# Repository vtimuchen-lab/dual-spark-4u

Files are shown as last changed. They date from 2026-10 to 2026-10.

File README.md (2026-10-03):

# dual-spark-4u — 5U-модуль с 2 × MSI EdgeXpert AI (DGX Spark-class) и раздельным охлаждением для 18U шкафа

Параметрический OpenSCAD-проект самостоятельного 5U-узла: фронтальная панель
ЦМО ФП-5 с двумя вырезами под 140-мм вентиляторы, алюминиевая base_plate на
полке шкафа, два holder'а (адаптация
[alexliesenfeld/dgx-spark-printables](https://github.com/alexliesenfeld/dgx-spark-printables),
CC BY-NC 4.0), два независимых воздуховода 140 → передняя решётка MSI, свободный
выхлоп в горячую зону шкафа. Имя репозитория историческое: v1 проектировалась
под 4U-корпус (`docs/TZ_v1_chassis.md`), v2 — модуль в шкафу (`docs/TZ.md`).

```
[решётка ARCTIC 140] → [ФП-5] → [Arctic P14 Pro PST 27] → [duct 120] → [EPDM 5] → [MSI 151] → [выхлоп ≥ 90]
                                   × 2 трака, оси x = ±98 от центра панели
```

## Статус: PREVIEW — ждёт пять замеров шкафа

Сборка модуля, base_plate и вертикальная разметка панели **не собираются**, пока
в `scad/params.scad` стоят `undef` для `rack_opening_w`, `shelf_top_z`,
`shelf_depth`, `panel_t`, `panel_hole_pitch_v` (`docs/03_measure_checklist.md`,
п.1–5). Детали, не зависящие от шкафа (holder, воздуховод, заслонка, уголок,
стойка DC), собираются и лежат в `stl/*_PREVIEW.stl`; рендеры сборки сделаны на
подстановочных значениях, перечисленных в `scripts/export_all.sh` и
`docs/02_layout.md` §7.

| Документ | Что |
|---|-----|
| `docs/TZ.md` | ТЗ v2 (принятые решения) |
| `CLAUDE.md` | решения, открытые вопросы, журнал |
| `docs/01_analysis.md` | MSI EdgeXpert, исходник holder'а, опыт сообщества (+архив анализа 4U) |
| `docs/02_layout.md` | размерная схема модуля, координаты, проверки |
| `docs/03_measure_checklist.md` | что измерить (шкаф, панель, MSI, покупные) |
| `docs/04_aero_estimate.md` | расход, характеристика P14 Pro PST, рабочая точка, байпас, дверь шкафа |
| `docs/05_bom_hardware.md` | печатные/покупные части, крепёж, длина болтов |
| `docs/06_dimensions.md` | таблица размеров |
| `docs/07_rack_layout.md` | раскладка 18U, холодная/горячая зона, датчики, установка/снятие |
| `docs/drawings/` | `panel_fp5`, `base_plate`, `side_view`, `top_view` (SVG + PNG) |
| `docs/renders/` | 3D-превью (`*_PREVIEW.png`) |

## Ключевые размеры

| | мм |
|---|---|
| Трак / шаг / пара | 181 / 196 / 377 |
| Длина модуля от задней плоскости панели | 393 (шкаф 600) |
| Ось вентилятора над полкой / над плитой | 78 / 75 (= ось MSI) |
| Вырезы панели | 2 × Ø138 на 143.3 и 339.3 от левого края; ось по вертикали = `shelf_top_z` + 78 ∈ [90; 131.5] |
| Воздуховод | 135×135 → 145×57, plenum 50 + nozzle 70, стенка 2.4 |
| Болт сэндвича | M4×40 при panel_t 1.0–2.0 |
| Контроллеры | в рамках на лицевой стороне панели над вентиляторами; полоса = 221.5 − `shelf_top_z` − 150 |

## Файлы

```
scad/params.scad          все параметры [SRC]/[ASSM]/TO_MEASURE(undef), производные, part_checks()/rack_checks()
scad/lib/shapes.scad      примитивы, лофт, макеты
scad/edgexpert_holder.scad  holder (part=holder|holder_with_device|baffle|holder_with_baffle)
scad/duct.scad            воздуховод (part=duct|duct_a|duct_b|duct_section)
scad/front_panel.scad     ФП-5 с вырезами (part=panel|panel_2d) — требует TO_MEASURE
scad/base_plate.scad      base_plate (требует TO_MEASURE), panel_bracket, dc_jack_bracket
scad/ctrl_bezel.scad      рамка термоконтроллера на лицевой стороне ФП-5 (требует ctrl_w/h/d)
scad/assembly.scad        модуль (part=module|exploded|track|printables)
scad/fan_bracket.scad     ОПЦИЯ: рамка для настольного стенда
stl/                      *_PREVIEW.stl до заполнения TO_MEASURE
scripts/export_all.sh     пересборка STL, рендеров, чертежей (суффикс PREVIEW автоматически)
scripts/make_drawings.py  чертежи из params.scad
```

## Как пользоваться

1. Измерить п.1–5 (и по возможности B/C) из `docs/03_measure_checklist.md`,
   вписать в `scad/params.scad` вместо `undef`.
2. `./scripts/export_all.sh` — при полных параметрах суффикс `_PREVIEW`
   исчезает, рендеры и чертежи пересчитываются на реальных размерах; в выводе не
   должно быть `ERROR: Assertion`.
3. Резать панель и сверлить плиту по `docs/drawings/panel_fp5.svg` и
   `base_plate.svg`; печатать по `docs/05_bom_hardware.md` (PETG прототип, ASA
   финал); собирать по `docs/07_rack_layout.md` §5.

Ручной экспорт одной детали:

```sh
openscad -o stl/edgexpert_holder.stl scad/edgexpert_holder.scad
openscad -o stl/bypass_baffle_050.stl -D 'part="baffle"' -D bypass_block=0.5 scad/edgexpert_holder.scad
openscad -o stl/duct.stl scad/duct.scad
openscad -o stl/panel_bracket.stl -D 'part="panel_bracket"' scad/base_plate.scad
```

## Лицензия

Производная работа от dgx-spark-printables (CC BY-NC 4.0, Alexander Liesenfeld) —
на тех же условиях, некоммерчески, с указанием автора исходника.

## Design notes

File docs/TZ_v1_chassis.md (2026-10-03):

# ТЗ v1 (исходное): система размещения и принудительного охлаждения 2× MSI EdgeXpert AI / DGX Spark-class в одном 4U корпусе

> Архивная версия. Заменена `docs/TZ.md` (v2: 5U-модуль в 18U шкафу).
> Текст сохранён как получен, без правок.

## 1. Цель проекта
Спроектировать внутреннюю механическую конструкцию для существующего металлического rackmount-корпуса 4U, позволяющую установить внутри два компьютера MSI EdgeXpert AI на NVIDIA GB10 и организовать для каждого отдельный управляемый воздушный тракт.
Требуется не новый корпус и не передняя rack-панель. Существующий 4U-корпус уже имеется и должен использоваться как внешнее шасси.
Основная идея:
один корпус 4U → два MSI EdgeXpert → две отдельные подставки → два независимых воздуховода → по одному 140-мм вентилятору на каждый EdgeXpert.
В качестве механической основы под каждый EdgeXpert использовать и адаптировать конструкцию holder из проекта:
`https://github.com/alexliesenfeld/dgx-spark-printables`
Основной исходник для изучения:
`spark-rack-10/dgx_spark_rack_mount.scad`
Не использовать 10-дюймовую переднюю панель этого проекта. Нужен только принцип и геометрия внутреннего holder / основания / ложемента.

## 2. Исходные данные
В репозитории для DGX Spark-class используется расчетный габарит устройства:
150 × 150 × 50,5 мм.
В исходном `spark-rack-10`:
* `device_width = 150 mm`
* `device_depth = 150 mm`
* `device_height = 50.5 mm`
* нижняя конструкция имеет вентиляционные каналы;
* имеются боковые направляющие;
* имеются задние ограничители;
* верх устройства открыт;
* holder экспортируется отдельно через `part="holder"`;
* исходная конструкция рассчитана на 2×80 мм вентилятора, расположенные перед устройством.

Размеры исходного holder приблизительно:
183 мм ширина × 182,5 мм глубина × до 88 мм высота передней части.
Эти размеры рассматривать только как исходные параметры. Перед окончательной моделью необходимо проверить реальные размеры конкретного MSI EdgeXpert AI, расположение его ножек, нижних, передних, боковых и задних вентиляционных отверстий.
Фотографии существующего 4U-корпуса предоставлены отдельно. Конструкцию проектировать именно для этого корпуса.

## 3. Что использовать из GitHub-модели
Из `spark-rack-10` необходимо взять за основу нижний holder, а именно:
* основание;
* опорные продольные элементы;
* вентиляционные каналы снизу;
* боковые направляющие;
* задние стопоры;
* принцип свободного доступа воздуха снизу и сбоку.

НЕ использовать:
* 254×88 мм front panel;
* rack ears;
* отверстия под крепление 10-inch rack;
* существующие отверстия под 2×80 мм вентиляторы;
* саму переднюю панель вообще.

Holder должен стать самостоятельной подставкой, закрепленной на металлическом дне существующего 4U-корпуса.
Желательно сделать крепление holder к корпусу съемным, например M3/M4, резьбовые заклепки, закладные гайки либо отдельная металлическая монтажная пластина.
Не рассчитывать только на клей или двусторонний скотч.

## 4. Количество оборудования
В одном корпусе устанавливаются: 2 × MSI EdgeXpert AI / GB10.
Не два rack-корпуса. Не 12 вентиляторов. Не 4×80 мм.
Основной вариант проекта: 2 × 140-мм вентилятора 12 В, по одному вентилятору на каждый EdgeXpert.
Каждый EdgeXpert имеет свой отдельный воздушный тракт.

## 5. Предпочтительное размещение EdgeXpert
Приоритетное расположение — два устройства рядом в одном горизонтальном слое, если реальные внутренние размеры корпуса позволяют.
Не размещать один EdgeXpert над другим без серьезной причины.
Причины: одинаковые условия охлаждения; прямые воздуховоды; более простой монтаж; удобный доступ к обоим устройствам; отсутствие нагрева верхнего устройства нижним; возможность снять одно устройство независимо от второго.
Ориентацию каждого MSI подобрать так, чтобы штатное направление внутреннего воздушного потока совпадало с направлением внешней вентиляции.
Желательное направление всего корпуса: перед корпуса → EdgeXpert → зад корпуса.

## 6. Основная схема охлаждения
Для каждого компьютера:
```
холодный воздух → [140×140×25 FAN] → [пленум / плавный переход] → [входные отверстия EdgeXpert]
→ [штатная система охлаждения EdgeXpert] → горячий воздух → задняя часть 4U-корпуса
```
Внешний вентилятор не должен просто обдувать весь корпус. Его воздух необходимо направить преимущественно именно к воздухозабору EdgeXpert.
При этом нельзя герметично закрывать вентиляционные отверстия устройства, которые MSI использует дополнительно снизу или по бокам.
Поэтому перед окончательным проектом требуется определить реальную аэродинамическую схему MSI EdgeXpert.

## 7. Вентиляторы
Основной расчет вести под стандартный вентилятор: 140 × 140 × 25 мм, 12 В, PWM. Один вентилятор на один EdgeXpert. Итого: 2 вентилятора на весь корпус.
Крепление вентилятора должно быть стандартным и позволять его замену без печати нового воздуховода.
Предусмотреть: стандартные 140-мм монтажные отверстия; M4 или стандартные fan screws; возможность установки резиновых виброразвязок; съемную рамку; опциональную защитную решетку; опциональный воздушный фильтр только при малом аэродинамическом сопротивлении.
Не проектировать плотную декоративную решетку перед крыльчаткой.

## 8. Воздуховод
Необходимы два отдельных воздуховода: FAN 1 → duct 1 → EdgeXpert 1; FAN 2 → duct 2 → EdgeXpert 2.
Не делать один общий воздуховод с двумя входами без специального CFD-обоснования.
Каждый канал должен начинаться с 140×140 мм. Конечная геометрия выхода должна определяться по реальному воздухозабору MSI EdgeXpert, а не только по внешнему размеру корпуса 150×50,5 мм.
Предварительный ориентир выхода воздуховода: около 150–155 мм шириной, высота определяется реальной зоной воздухозабора. Не считать `152 × 54 мм` окончательным размером.

## 9. Геометрия перехода
Не делать резкое сужение. Нужен плавный diffuser/nozzle. Допустимая исходная длина воздуховода: 100–180 мм.
Если глубины достаточно, предпочтительнее плавная форма с большим радиусом, чем короткая воронка.
Избегать: острых внутренних углов; ступенек; резких изменений площади; плоской стенки непосредственно за ступицей вентилятора.
Внутренние переходы желательно делать радиусными. Ориентировочный внутренний радиус: R15–R25 мм или больше.

## 10. Пленум за вентилятором
Не ставить EdgeXpert непосредственно вплотную к крыльчатке 140 мм. Желательно иметь участок выравнивания потока: примерно 40–80 мм от плоскости вентилятора до начала критического сужения/входа устройства.
При необходимости добавить внутренние направляющие лопатки: тонкие; с закругленной передней кромкой; без значительного сопротивления; распределяющие поток по ширине воздухозабора.

## 11. Задняя часть корпуса
После EdgeXpert горячий воздух должен иметь свободное пространство для выхода. Минимально желательно 70–100 мм свободной зоны после устройства.
Не ставить непосредственно за выходом EdgeXpert глухую стенку.
Предусмотреть возможный будущий вариант: общий задний exhaust plenum; 1×140 мм exhaust; либо 2×120/140 мм exhaust. Первый прототип должен работать и без дополнительной задней принудительной вытяжки. Задний exhaust-модуль опциональный.

## 12. Боковые и нижние отверстия MSI
Нельзя проектировать holder так, чтобы: закрыть нижний воздухозабор; перекрыть боковые решетки; полностью зажать корпус MSI пластиковыми стенками.
Перед моделированием изучить: реальную нижнюю поверхность MSI EdgeXpert; расположение ножек; решетки; вход/выход воздуха; разъемы; кнопку питания; доступ к LAN/USB/питанию.

## 13. Основание / holder
На каждый EdgeXpert отдельный holder. Holder должен: удерживать от бокового и продольного смещения; не пережимать корпус; сохранять вентиляцию снизу; позволять снять устройство; крепиться к металлическому основанию корпуса; выдерживать транспортировку.
Толщина печатных несущих стенок: 4–5 мм. Нижние элементы: 4–5 мм. Аэродинамическая оболочка воздуховода: 2–3 мм.

## 14. Разделение holder и воздуховода
Модульность: [fan bracket] + [air duct] + [EdgeXpert holder], соединение винтами/защелками/пазами.

## 15. Материал
PETG, ASA или ABS. PLA не использовать. PETG для прототипа, ASA для окончательной версии.

## 16. Электрика вентиляторов
12 В PWM, 4-pin. Место для PWM-контроллера, температурного датчика, распределителя питания, кабелей. Электроника не в горячем выхлопе. Ручное и автоматическое управление оборотами.

## 17. Возможные датчики
Перед воздухозабором EdgeXpert; за EdgeXpert; внутри корпуса; при необходимости — duct.

## 18. Расположение в существующем 4U корпусе
Определить по фото: внутреннюю ширину, высоту, глубину, положение HDD-корзины, существующие вентиляторы, заднюю панель, PCI-слоты, кабели, переднюю панель. Указать, что демонтировать. Не предлагать новый корпус, пока не доказано обратное.

## 19. Предпочтительная компоновка сверху
Два тракта рядом: [140 FAN] → [DUCT] → [MSI #1] →; [140 FAN] → [DUCT] → [MSI #2] → rear exhaust. Потоки независимые.

## 20. Ориентация корпуса MSI
Определить реальный intake → internal airflow → exhaust, затем ориентировать устройство в holder.

## 21. CFD / аэродинамическая оценка
Инженерная оценка: площади, отношение площадей, скорость, зоны рециркуляции, потери на переходе, ступица, решетка. Указать проблемные места. Не выдавать CFM вентилятора за расход через EdgeXpert.

## 22. Передняя панель существующего корпуса
Оценить достаточность вентиляционных отверстий дверцы для двух 140-мм. При необходимости — увеличение перфорации, сетка, два окна, съемный фильтр. Вентиляторы могут стоять глубже внутри корпуса.

## 23. Шум
Низкие обороты в idle; PWM только под нагрузкой; без свиста; расстояние от решетки; без близкой перфорации перед лопастями.

## 24. Сервисное обслуживание
Снять крышку; вынуть каждый EdgeXpert отдельно; заменить вентилятор; снять duct; доступ к разъемам; очистка фильтров; кабели. Извлечение Spark №1 не требует демонтажа Spark №2.

## 25. Кабели
Место и фиксаторы для питания, Ethernet, USB, HDMI/DP, PWM. Не пересекать выхлоп и duct. Strain relief.

## 26. Крепеж
M3 для печатных деталей; M4 основные; heat-set inserts; M4/M5 к шасси. Без саморезов в пластик в местах разборки.

## 27. 3D-печать
Детали под стол 250 × 250. Воздуховод при превышении — 2 части с фланцем/пазом/tongue-and-groove без внутренней ступеньки.

## 28. Параметрическая модель
OpenSCAD/FreeCAD; параметры в верхней части файла: размеры MSI, вентилятор, расстояние вентилятор–устройство, длина duct, выход, стенки, отверстия.

## 29. Требуемый результат
Этап 1 — анализ; Этап 2 — размерная схема (сверху/сбоку/спереди); Этап 3 — holder; Этап 4 — duct; Этап 5 — файлы (SCAD, STL, STEP, сборка, exploded, крепеж, таблица размеров).

## 30. Обязательная проверка перед финальной STL
Запросить: внутреннюю ширину/высоту/глубину 4U; точный размер MSI; ножки; фото MSI снизу; фото вентиляции; отверстия дна; модель 140-мм вентилятора. Неизвестное — `TO_MEASURE`.

## 31. Критерий успешного проекта
Один существующий 4U корпус + два MSI + два holder + два 140-мм PWM + два плавных воздуховода. Воздух спереди; каналы независимые; штатное охлаждение сохранено; нижняя и боковая вентиляция не блокируется; выхлоп назад; устройства легко снимаются; PETG/ASA; без 10″ панели.
Приоритет: аэродинамика и надёжность → обслуживание → компактность и вид. Не рендер, а инженерный проект: каждое размерное решение обосновано или помечено как предположение.

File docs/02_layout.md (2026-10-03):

# Этап 2 — размерная схема 5U-модуля

Чертежи генерируются из `scad/params.scad` скриптом `scripts/make_drawings.py`:

| Чертёж | Файл | Статус |
|---|---|---|
| Разметка панели ФП-5 (вырезы, пазы M4) | `drawings/panel_fp5.svg/.png` | горизонталь окончательна; вертикаль — по формуле, пока `shelf_top_z` TO_MEASURE |
| Сверловка base_plate | `drawings/base_plate.svg/.png` | отверстия относительно оси и переднего края окончательны; габарит TO_MEASURE |
| Вид сбоку, один трак | `drawings/side_view.svg/.png` | окончателен |
| Вид сверху, модуль | `drawings/top_view.svg/.png` | ширина плиты условна |
| 3D-превью | `renders/*_PREVIEW.png` | на подстановочных значениях (см. §7) |

## 1. Система координат модуля

* X — ширина, 0 на оси панели/плиты, вправо +;
* Y — глубина, 0 — задняя плоскость панели ФП-5 (лист в y < 0), назад +;
* Z — высота, 0 — верх полки (= низ base_plate).

## 2. Продольная цепочка трака (y, мм)

| y | Элемент |
|---|---|
| −(panel_t + 3) … −panel_t | решётка ARCTIC 140 (снаружи) |
| −panel_t … 0 | лист ФП-5 (`panel_t` TO_MEASURE); отбортовка 10 мм уходит в +Y по периметру |
| 0 … 27 | Arctic P14 Pro PST 140×140×27 |
| 27 … 33 | входной фланец воздуховода 150×150×6, 4 гнезда гаек M4 |
| 33 … 77 | пленум 135×135 |
| 77 … 141 | сопло 135×135 → 145×57 |
| 141 … 147 | выходной фланец 181×78×6, 4×M3 в стойки holder'а |
| 147 … 152 | EPDM 5 |
| 152 … 303 | MSI EdgeXpert 151 |
| 303 … 307 | задний стопор |
| 303 … 393 | свободный выхлоп 90 |

Holder: y = 147…307, ширина 181, стойки 109 над плитой. base_plate: y = 2…(≥ 332),
глубина по полке. Полная длина модуля от задней плоскости панели — **393 мм**,
плюс кабели сзади ~80 → в шкафу 600 мм помещается с запасом.

## 3. Поперечная раскладка (x от оси)

| x | Что |
|---|-----|
| ±98 | оси траков (вентиляторы, воздуховоды, MSI); шаг 196 |
| ±7.5 … ±188.5 | holder'ы (181 каждый, зазор между ними 15) |
| ±23 … ±173 | воздуховоды (150) и входные фланцы |
| ±178 … ±208 | уголки panel↔base_plate (30 шт. ширина, центр ±193) |
| ±175 … ±(плита/2 − 2) | полосы электроники (≈45 мм при проёме 450.85) |
| ±(rack_opening_w/2 − 3) | края base_plate |
| ±241.3 | края панели ФП-5 |

Вырезы Ø138 на панели: центры на 143.3 и 339.3 мм от левого края панели, 196 между ними.

## 4. Вертикаль (z над полкой)

| z | Что |
|---|-----|
| 0…3 | base_plate |
| 3…8 | дно holder'а |
| 8…148 | вентилятор (ось **78** = плита 3 + 75) |
| 52 | дно MSI (ось MSI = 78) |
| 104 | верх MSI |
| 112 | верх стоек holder'а |
| 148 | верх вентилятора/фланца; панель 221.5 высотой |

На панели (z от нижнего края ФП-5): ось выреза = `shelf_top_z + 78`, допустимо
**90…131.5** (фланец 150 ≥ 15 мм от краёв) ⇒ `shelf_top_z ∈ [12; 53.5]`.
Если полка не попадает в этот диапазон — переставить её на один U-шаг (44.45)
либо изменить `fan_axis_above_plate` (тогда пересчитать высоту holder'а —
автоматически).

## 5. Панель ФП-5 — что делается

Два выреза Ø138 (лобзик/коронка/лазер) и 8 пазов 4.5×5.5 мм (сверло 4.5 +
надфиль по диагонали — под межцентровое 124.5/125). Отверстия уголков: 2×Ø4.5
на x = ±193 от оси, z = `shelf_top_z` + 20 и + 51. Над каждым вентилятором —
2×Ø3.4 под лапки рамки контроллера (x = ±98 ± (bezel_w/2 + 5)) и Ø12 под втулку
кабелей (снаружи от рамки), все на z = `shelf_top_z` + 150 + bezel_h/2.
Крепёжные уши — без изменений. Резать только после замера `shelf_top_z` и
габаритов контроллера (чертёж `panel_fp5` перестроится).

## 6. Электроника

**Контроллеры** — на лицевой стороне панели над вентиляторами, по оси трака, в
печатных рамках `ctrl_bezel` (TZ §4.1). Полоса под рамку =
221.5 − `shelf_top_z` − 150 (46.5 мм при shelf_top_z = 25); глубина рамки
≈ ctrl_d + 4.5 должна быть ≤ `door_gap` − 3. Кабели вентилятора, 12 В и датчика
проходят через Ø12 с втулкой рядом с рамкой; датчик — назад вдоль наружной
стенки holder'а в гнездо T_out.

**На base_plate** — две полосы по бокам (x = ±175…±~220, y = 59…141), сетка M3
шаг 10: слева WAGO 221-413 «+»/«−», справа стойка DC-гнезда (гнездо смотрит
назад).

## 7. Подстановочные значения для PREVIEW-рендеров

Сборка не собирается при `undef`. Для картинок `scripts/export_all.sh` передаёт
**не измерения, а подстановки**: `rack_opening_w = 450.85` (EIA-310 номинал),
`shelf_top_z = 25`, `shelf_depth = 400`, `panel_t = 1.2`,
`panel_hole_pitch_v = 31.75`, `ctrl_w/h/d = 60/35/20`, `door_gap = 40`. Ни одно из них
не является размером вашего шкафа или контроллера.

## 8. Проверки в модели

`rack_checks()` (assert): пять TO_MEASURE заданы; плита шире пары траков;
уголки внутри плиты и keep-out панели; полосы электроники ≥ 30 мм; ось выреза в
допуске; полка ≥ 330 и несёт модуль; модуль короче шкафа; `ctrl_checks()`:
габариты контроллера и `door_gap` заданы, рамка влезает в полосу над
вентилятором, не упирается в стекло, лапки и Ø12 в keep-out и выше фланца. `part_checks()`:
детали помещаются на стол 250×250, площадь выхода < входа.

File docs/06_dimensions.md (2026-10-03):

# Таблица размеров (v2, значения из `scad/params.scad`)

Статус: [SRC] источник; [ASSM] допущение; TO_MEASURE — `undef` в модели.

## Шкаф, полка, панель

| Размер | Значение | Статус |
|---|---|---|
| Шкаф: высота / глубина | 18U / 600 | [SRC] |
| Проём между передними стойками | `rack_opening_w` | TO_MEASURE п.1 (EIA-310 номинал 450.85) |
| Верх полки от нижнего края ФП-5 | `shelf_top_z` ∈ [12; 53.5] | TO_MEASURE п.2 |
| Глубина полки | `shelf_depth` ≥ 330 | TO_MEASURE п.3 |
| ФП-5: Ш × В / отбортовка / лист | 482.6 × 221.5 / 10 / `panel_t` | [SRC] / [SRC] / TO_MEASURE п.4 |
| Шаг отверстий в ушах ФП-5 | `panel_hole_pitch_v` | TO_MEASURE п.5 |
| Keep-out от краёв панели | 15 | [SRC ТЗ v2] |

## Панель — разметка

| Размер | Значение |
|---|---|
| Вырезы | 2 × Ø138, центры x = 143.3 и 339.3 от левого края (±98 от оси) |
| Ось вырезов по вертикали | `shelf_top_z` + 78, допуск 90…131.5 от нижнего края |
| Пазы M4 | 8 × (4.5 × 5.5) на □124.5 вокруг каждого центра |
| Отверстия уголков | 4 × Ø4.5 на x = ±193, z = `shelf_top_z` + 20 / + 51 |
| Рамки контроллеров | над вентиляторами, низ на z = `shelf_top_z` + 150; габарит (ctrl_w + 6.8) × (ctrl_h + 6.8) × (ctrl_d + 4.5) — TO_MEASURE п.23 |
| Отверстия рамок | 2 × Ø3.4 на x = ±98 ± (bezel_w/2 + 5), z = `shelf_top_z` + 150 + bezel_h/2 |
| Втулки кабелей | 2 × Ø12 на x = ±(98 + bezel_w/2 + 18), z как у лапок |
| Полоса над вентилятором | 221.5 − `shelf_top_z` − 150 |

## Base plate и уголки

| Размер | Значение | Статус |
|---|---|---|
| Плита: толщина / ширина / глубина | 3 / `rack_opening_w` − 6 / ≥ 330 (≤ полка) | [SRC] / расчёт / TO_MEASURE |
| Передний край плиты от задней плоскости панели | 2 | [ASSM] |
| Отверстия holder'ов | 2 × 4 × Ø4.5 на 140 × 120 вокруг (±98; y = 227.5) | [ASSM] |
| Отверстия уголков | 2 × 2 × Ø4.5 на x = ±193, y = 19 / 40 | [ASSM] |
| Полосы электроники | x = ±175…±(плита/2 − 2), y = 59…141, сетка M3 10 | расчёт |
| Уголок Ш × Г × В / толщина | 30 × 50 × 60 / 5 | [ASSM] |

## Трак

| Размер | Значение |
|---|---|
| Ширина трака / шаг / пара | 181 / 196 / 377 |
| Длина модуля от задней плоскости панели | 393 |
| Ось вентилятора (над полкой / над плитой) | 78 / 75 |
| Дно / верх MSI над полкой | 52 / 104 |
| Вентилятор | Arctic P14 Pro PST 140 × 140 × 27, отверстия □124.5 ±0.5 |
| Решётка снаружи | ARCTIC Fan Grill 140, `grille_t` = 3 [ASSM] |
| Болт сэндвича | M4 × 40 (стек 37–38 при panel_t 1.0–2.0) |

## Воздуховод

| Размер | Значение |
|---|---|
| Входной фланец | 150 × 150 × 6, 4 гнезда гаек M4 |
| Вход внутр. | 135.2 × 135.2, R12 |
| Пленум / сопло | 50 / 70 (вкл. фланцы), всего 120 |
| Выход внутр. | 145 × 57, R6 (заход под дно MSI 8) |
| Отношение площадей | 2.21 |
| Выходной фланец | 181 × 78 × 6; 4 × M3 на x = 5 / 176, z = 55 / 97 (над плитой) |
| Стенка | 2.4 |

## Holder

| Размер | Значение |
|---|---|
| Габарит Ш × Г × В | 181 × 160 × 109 (над плитой) |
| Дно / стенки | 5 / 5 |
| Рельсы | 4 × 20 × 49; центры x = 35 / 72 / 109 / 146 (внешние — под ножками MSI при inset 20); каналы 17 |
| Отступ рельсов от края MSI | 9 (= inset 20 − Ø16/2 − 3) |
| Боковой зазор к MSI | 10 |
| Низкие направляющие над дном MSI | 15 |
| Передние стойки Ш × Г | 10 × 25 |
| Задние стопоры | 2 × (10 × 3), высота дно + 10 |
| Пазы к плите | 4 × (4.5 × 10), цековка Ø9, шаг 140 × 120 |
| Заслонка байпаса | гребёнка 3 мм, пальцы 15, высота = `bypass_block` × 44 |

## Устройство (MSI EdgeXpert MS-C931)

| Размер | Значение | Статус |
|---|---|---|
| Ш × Г × В | 151 × 151 × 52 | [SRC] / TO_MEASURE п.9 |
| Рамка сот | 3 / 3 / 3 | [ASSM] п.11 |
| Ножки Ø / inset / высота | 16 / 20 / 4 | [ASSM] п.10 |

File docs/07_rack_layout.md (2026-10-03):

# Раскладка шкафа 18U и принцип охлаждения

## 1. Шкаф

18U, глубина 600 мм, стеклянная передняя дверь, перфорированная крыша, в верхнем
1U — вентиляторный модуль с термостатом (вытяжка вверх). Уходят: 4U-корпус,
NAS, UDM. Остаются: ИБП, патч-панель, коммутатор, полка с Mac, вентиляторный модуль.

Раскладка снизу вверх (U — снизу):

| U | Что | Спереди |
|---|-----|---|
| 1–2 (по ИБП) | ИБП | лицевая панель ИБП |
| +5 | **5U-модуль Spark'ов** на полке | ФП-5 с двумя вырезами Ø138 + решётки ARCTIC 140 |
| +5 | сервисный запас | ФП-5 глухая (съёмная; при обслуживании — доступ сверху к модулю) |
| +1…+3 | патч-панель, коммутатор, полка с Mac | штатные панели; пустоты — ФП-1/2 глухие |
| 18 | 1U вентиляторный модуль с термостатом | — |

Точные номера U зависят от высоты ИБП — заполнить после установки.

## 2. Холодная и горячая зоны

* **Холодная зона** — объём между стеклянной дверью и передними стойками.
  Воздух в неё поступает через зазоры двери (низ/бока) и, если есть, через
  перфорацию нижней части двери/цоколя.
* **Горячая зона** — всё за передними стойками. Выхлоп MSI (зад и бока) выходит в
  неё; 1U вентиляторный модуль вытягивает её вверх через перфорированную крышу.
* Вентиляторы трактов берут воздух **только** из холодной зоны: панель ФП-5
  плотно стоит на стойках, фланцы воздуховодов прижаты к панели, EPDM — между
  фланцем выхода и MSI.
* Чтобы горячий воздух не возвращался в холодную зону: все пустые юниты спереди
  закрыты **глухими** заглушками ЦМО ФП-1/2/4/5 (не перфорированными «.4»),
  боковые щели между стойками и боковинами — щёточный уплотнитель или поролон
  по всей высоте. Проверка: при работе под нагрузкой T в холодной зоне
  (датчик у решётки) не растёт относительно комнаты более чем на 2–3 °C.

Если холодная зона всё же греется (стеклянная дверь без перфорации), варианты:
приоткрыть дверь на фиксаторе; сетчатая вставка в нижней трети двери; доп.
120-мм вентилятор в цоколе на вдув. Это главная неизвестная проекта
(`04_aero_estimate.md` §5).

## 3. Датчики и термостат

| Датчик | Где | Для чего |
|---|-----|---|
| T_out ×2 | гнездо в holder'е за задней решёткой каждого MSI | вход PWM-термоконтроллера своего тракта |
| T_in (опц.) ×2 | гнездо во входной стойке holder'а / отверстие в выходном фланце duct | ΔT тракта, проверка холодной зоны |
| Термостат 1U-модуля | сзади, 20–30 см выше модуля Spark'ов, вне прямого выхлопа (на задней стойке или боковине) | порог ~35 °C |
| T_cold (опц.) | в холодной зоне у решётки | контроль рециркуляции |

## 4. Электрика модуля

Внутри модуля: гнездо DC 5.5×2.5 (на стойке в правой полосе base_plate, смотрит
назад) → WAGO 221-413 «+» и WAGO 221-413 «−» (левая полоса) → через Ø12 с
втулкой в панели → 2 PWM-термоконтроллера 12 В 4-pin 25 кГц в рамках на лицевой
стороне панели над вентиляторами → P14 Pro PST (каждый контроллер — свой тракт,
датчик в T_out своего MSI, провод датчика назад вдоль наружной стенки holder'а).
Контроллеры стоят в холодной зоне, дисплеи видны через стекло; рамка выступает
на ≈ ctrl_d + 4.5 мм и должна проходить под дверью (`door_gap` − 3).
Минимум PWM на контроллерах ≥ 15–20 % (P14 Pro останавливается при PWM < 5 %;
автостоп запрещён). Адаптер 12 В / 2 А стоит в горячей зоне шкафа (на полке за
модулем или на боковине), штекер входит сзади.

Перспектива (место заложено, не реализуется): ESP32 + DS18B20 в тех же гнёздах,
управление по температуре GPU из `nvidia-smi` по сети, резерв на датчики при
потере связи, fail-safe — 100 % PWM при любой ошибке.

Наружу из модуля выходят только штекер 12 В и кабели Spark'ов (DC-in, 10GbE/QSFP,
USB-C) — назад, через выхлопную зону, с запасом по длине на выдвижение.

## 5. Установка модуля

1. На столе: base_plate → holder'ы (8×M4) → уголки (4×M4 к плите) → воздуховоды
   (по 4×M3 в стойки holder'ов) → панель: уголки к панели (4×M4), вентиляторы и
   решётки в сэндвич (8×M4×40), втулки Ø12, рамки с контроллерами (винты M3
   сзади панели) → WAGO, DC-гнездо, разводка 12 В и датчики через втулки →
   EPDM на выходные фланцы → MSI в holder'ы, ремни.
2. В шкафу: полка на нужной высоте (`shelf_top_z` 12…53.5 мм ниже нижнего края
   ФП-5 — см. `panel_fp5.svg`). Модуль задвигается по полке, панель — на
   передние стойки штатными винтами M6 (4 шт.).
3. Подключить кабели Spark'ов и 12 В сзади. Проверить вращение обоих
   вентиляторов на минимальном PWM.
4. Поставить заглушки пустых юнитов, уплотнить боковые щели, закрыть дверь.

## 6. Снятие и обслуживание

* **MSI отдельно:** снять заглушку сервисного 5U сверху (или выдвинуть модуль на
  полке на 100 мм), отстегнуть ремень, поднять MSI вверх из holder'а. Второй MSI
  не трогается.
* **Вентилятор:** снаружи — снять решётку и 4 болта сэндвича; вентилятор
  вынимается вперёд через панель? Нет — вентилятор 140 больше выреза 138:
  вынимается внутрь после снятия панели с уголков (4×M4) либо выдвижения модуля.
  Поэтому сэндвич не затягивать «намертво»: болты M4 с нейлоновыми шайбами.
* **Воздуховод:** 4×M3 с передней стороны holder'а, после снятия вентилятора.
* **Весь модуль:** 4 винта панели, вытянуть по полке вперёд. Кабели Spark'ов и
  12 В отключаются сзади заранее.

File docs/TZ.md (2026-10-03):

# ТЗ v2: 5U-модуль с двумя MSI EdgeXpert AI в 18U шкафу

Версия 2 заменяет `docs/TZ_v1_chassis.md` (вариант «внутри 4U-корпуса»).
Правила раздела 8 — без изменений относительно v1.

## 1. Размещение

* Шкаф 18U, глубина 600 мм, стеклянная передняя дверь, перфорированная крыша,
  сверху 1U вентиляторный модуль с термостатом (вытяжка вверх).
* Из шкафа уходят: 4U-корпус, NAS, UDM. Остаются: ИБП (низ), патч-панель,
  коммутатор, полка с Mac, вентиляторный модуль.
* Раскладка снизу вверх: ИБП → 5U модуль Spark'ов → 5U сервисный запас
  (съёмная заглушка) → патч-панель, коммутатор, полка Mac → 1U вентиляторы.
* Принцип: холодная зона — между стеклом и передними стойками; горячая —
  внутри шкафа. Вентиляторы трактов берут воздух только из холодной зоны через
  фронтальную панель. Все пустые юниты спереди — глухие заглушки (ЦМО ФП-1/2/4/5,
  НЕ перфорированные «.4»), боковые щели — щёточный уплотнитель/поролон.
* Датчик термостата 1U-модуля: сзади, 20–30 см над модулем Spark'ов, вне прямого
  выхлопа; порог ~35 °C.

## 2. 5U-модуль

Самостоятельный узел: собирается на столе, ставится в шкаф целиком, опирается на
полку шкафа, панель крепится к передним стойкам штатными винтами.

Состав:

* Фронтальная панель ЦМО ФП-5, сталь, серая RAL 7035.
  `panel_w = 482.6` [SOURCE], `panel_h = 221.5` [SOURCE], отбортовка 10 мм внутрь
  [SOURCE], `panel_t = TO_MEASURE`. Два выреза Ø ~138 мм + по 4 отверстия M4 на
  квадрате 124.5 мм. Вырезы и фланцы — не ближе 15 мм к краям (отбортовка).
* `base_plate`: алюминий 3 мм (`base_plate_t = 3`), ширина = `rack_opening_w − 2×3`,
  глубина ≥ 330 (TO_MEASURE по полке). На ней holder'ы и зона электроники.
* 2 уголка panel↔base_plate (`part="panel_bracket"`, PETG/ASA, M4) — жёсткий L-узел.
* Отдельная деталь `fan_bracket` больше не нужна — её роль играет панель.
  Оставлена как опция для настольного стенда (`fan_bracket.scad`, не в основном
  экспорте).

Продольная цепочка (от лицевой стороны панели назад):
решётка ARCTIC Fan Grill 140 (снаружи) → панель → вентилятор 27 → входной фланец
duct → plenum + nozzle → EPDM 5 → MSI 151 → задний стопор → свободный выхлоп ≥ 90.
Длина стяжных болтов сэндвича пересчитывается с учётом `panel_t` и толщины решётки
(`sandwich_stack` в params.scad; таблица в `05_bom_hardware.md`).

Вертикаль: ось вентилятора = верх base_plate + 75 мм (принцип «ось MSI = ось
вентилятора» сохраняется). Проверка: при заданной высоте полки вырезы попадают в
221.5 мм панели с полями ≥ 15 мм — `rack_checks()` в params.scad.

## 3. Вентилятор: Arctic P14 Pro PST (ACFAN00314A)

* 140×140×27 мм (`fan_thickness = 27`), 242 г.
* Межцентровое отверстий 124.5 мм (у Arctic встречается «125») — отверстия/пазы
  с допуском ±0.5.
* 400–2500 об/мин, 186 м³/ч, 5.2 мм вод. ст., 0.35 А, FDB.
* 0 об/мин при PWM < 5 % → в docs и BOM: минимум PWM в контроллере ≥ 15–20 %,
  автостоп запрещён.
* `04_aero_estimate.md`: новая P/Q-характеристика, рабочая точка (нужно
  40–60 м³/ч на тракт ≈ 600–900 об/мин), сопротивление стеклянной двери/щелей как
  главная неизвестная.

## 4. Электрика

* Питание вентиляторов: адаптер 12 В / 2 А, вход в модуль через гнездо 5.5×2.5
  (проверить совпадение с штекером).
* Разводка 12 В: WAGO 221-413 (отдельно «+» и «−»).
* Управление: 2 готовых PWM-термоконтроллера 12 В 4-pin 25 кГц (по одному на
  тракт), датчик каждого — в гнезде T_out за своим MSI.
* Перспектива (не реализовывать сейчас, только заложить место и описать в docs):
  ESP32 + DS18B20 + управление по температуре GPU из nvidia-smi с резервом на
  датчики и fail-safe 100 %.
* Электроника — на base_plate сбоку, в холодной зоне у панели, вне выхлопа и вне
  воздуховодов. Наружу из модуля: штекер 12 В и кабели Spark'ов.

### 4.1. Термоконтроллеры (2 шт.) — на лицевой стороне ФП-5

* Над каждым вентилятором, по оси трака, в холодной зоне между стеклом и
  стойками: контроллер не греется от шкафа, дисплей виден через стеклянную
  дверь, провода к вентилятору короткие.
* Полоса над вентиляторами: от верха рамки вентилятора до верхнего края панели,
  `strip_above_fan = 221.5 − shelf_top_z − 150` (≈46 мм при shelf_top_z = 25;
  чем ниже полка относительно панели, тем больше полоса).
* `part="bezel"` (`ctrl_bezel.scad`): печатная рамка PETG/ASA под контроллер,
  крепление к панели 2 × M3 (heat-set в лапках, винты сзади панели), окно под
  дисплей и кнопки, задняя стенка 1.5 мм изолирует пайку от стали.
* В панели: отверстие Ø12 под втулку для проводов вентилятора, 12 В и датчика,
  рядом с каждой рамкой (снаружи от оси трака); провод датчика идёт внутрь
  модуля назад, к T_out за своим MSI.
* `panel_fp5.svg`: отверстия под лапки и Ø12 с размерами.
* TO_MEASURE: `ctrl_w`, `ctrl_h`, `ctrl_d` (габариты контроллера), окно
  `ctrl_win_w/h`, `door_gap` (стекло двери ↔ лицевая плоскость панели).
* assert: `bezel_h ≤ strip_above_fan`; `bezel_d ≤ door_gap − 3`; лапки и Ø12 в
  keep-out панели; Ø12 выше входного фланца воздуховода.
* Боковые полосы электроники на base_plate — только WAGO и DC-гнездо.
* Запасной вариант, если дверь не закрывается: контроллеры за панелью над
  воздуховодами, дисплей — в окно панели.

## 5. Аэродинамика — исправить

* Байпас под MSI: выход duct заходит на 8 мм ниже дна, каналы под устройством
  открыты назад → часть потока идёт мимо сот. Добавлен регулируемый
  щиток/заслонка в каналах (параметр `bypass_block = 0…1`, печатная гребёнка
  `part="baffle"`); описан в docs как предмет испытаний.

## 6. Параметры

Удалены `chassis_*` как основные. Добавлены (все TO_MEASURE, `undef`):

* `rack_opening_w` — проём между внутренними гранями передних стоек;
* `shelf_top_z` — положение верха полки относительно нижнего края ФП-5;
* `shelf_depth` — глубина полки;
* `panel_t` — толщина листа ФП-5;
* `panel_hole_pitch_v` — вертикальный шаг крепёжных отверстий в ушах ФП-5.

MSI: 151×151×52 как SOURCE, нужные TO_MEASURE (ножки, зона сот) — без изменений.

## 7. Документация и чертежи

* `docs/07_rack_layout.md`: раскладка шкафа, холодная/горячая зона, заглушки,
  места датчиков, порядок установки и снятия модуля.
* `docs/drawings/panel_fp5.svg`: разметка вырезов ФП-5 с размерами от краёв панели.
* `docs/drawings/base_plate.svg`: сверловка base_plate.
* `docs/03_measure_checklist.md`: под шкаф (rack-параметры выше + MSI).
* `docs/05_bom_hardware.md`: P14 Pro PST, ФП-5, решётки, base_plate, уголки,
  контроллеры, WAGO, блок питания, болты новой длины.
* Рендеры и 3D-превью сборки модуля.

## 8. Правила (без изменений)

Не придумывать размеры; модульность; детали ≤ 250×250 мм; не перекрывать нижние и
боковые решётки MSI; два независимых тракта; PETG прототип / ASA финал; M3
heat-set, M4 основные.

## 9. Организация репозитория

* `main` создан из `claude/4u-dual-edgexpert-cooling-dw0pmu`; работа в ветке,
  PR в `main`.
* STL в `stl/` помечаются `*_PREVIEW.stl`, пока не заполнены все TO_MEASURE.
* Неизвестные размеры = `undef`; `rack_checks()` — assert, модель не собирается
  на выдуманных числах. Детали, не зависящие от шкафа (holder, duct, уголок,
  заслонка), собираются.

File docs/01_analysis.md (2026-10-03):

# Этап 1 — анализ

> **v2:** вариант «внутри 4U-корпуса» (раздел 3) отменён — проект переведён на
> 5U-модуль в 18U шкафу (`docs/TZ.md`). Разделы 1, 2, 4 (устройство, исходник
> holder'а, опыт сообщества) остаются в силе. Раздел 3 сохранён как история.

Статус: **предварительный**. Размеры MSI частично не измерены — `TO_MEASURE`
(`03_measure_checklist.md`, раздел B).

## 1. MSI EdgeXpert AI (MS-C931) — что известно

| Параметр | Значение | Источник / статус |
|---|---|---|
| Габарит | **151 × 151 × 52 мм** | карточки MS-C931 у реселлеров (PB Tech, starryhope, hornington); одна карточка даёт 150×150×52. Официальная страница ipc.msi.com недоступна из сессии → **TO_MEASURE** |
| Масса | 1.2 кг | те же карточки |
| SoC / TDP | GB10, TDP SoC 140 Вт; пик системы 240 Вт (БП USB-C 240 Вт) | NVIDIA DGX Spark Power Clarification (forum), ServeTheHome: до ~200 Вт от розетки |
| Заявление MSI | «stays rock-solid above 200 W», до 15 °C холоднее референса | MSI blog «5 surprising secrets» |
| Воздушный тракт | **Передняя сотовая решётка во всю переднюю грань = ВХОД**. Выход — задняя решётка над разъёмами и, по описанию MSI, боковые решётки («both sides and the rear carry exhaust vents»). | MSI blog (пересказ в результатах поиска) → **проверить по живому устройству, п.17 чек-листа** |
| «FanDock» | патентованная схема воздуховода внутри устройства + «airflow-guiding structure» на задней панели против рециркуляции; не внешний аксессуар | MSI blog |
| Ножки | 4 круглые, по углам, **повышенные** («elevated stacking footpads» — зазор под днищем для SSD/VRM) | MSI blog; фото `spark-atom/images/msi.png` в dgx-spark-printables |
| Низ | в основном глухой; поле из 8 коротких щелей ближе к **переднему** краю по центру (по msi.png: нижний край фото = перед устройства) | msi.png + `generate_bottom_projection.py` (ориентация) |
| Внутренние вентиляторы (референс DGX Spark) | 2 × Delta NS8CC50, 12 В 0.5 А | ChargerLAB teardown (по сниппету) |
| Разъёмы | все сзади: DC-in, 4×USB-C, HDMI, 10GbE, 2×QSFP; кнопка питания сзади | MSI datasheet (пересказ) |

Вывод для конструкции:

* ориентация в holder'е: **сотовая передняя грань — к вентилятору**, разъёмы —
  назад, к задней панели 4U. Логотип при этом смотрит вверх, но это следствие,
  а не причина (ТЗ п.20);
* верх глухой → воздуховод не должен подавать воздух сверху;
* низ: оставить открытыми каналы под устройством и подать часть потока под
  днище (выход воздуховода заходит на 8 мм ниже дна устройства —
  `outlet_under_device`), чтобы нижняя щелевая решётка у переднего края и
  зазор под ножками получали холодный воздух;
* боковые стенки holder'а рядом с устройством — **низкие** (15 мм над дном
  устройства), чтобы не перекрыть боковые решётки выхлопа; передние стойки
  высокие только на первых 25 мм глубины.

## 2. Что взято из `spark-rack-10/dgx_spark_rack_mount.scad`

Исходник проанализирован целиком (см. клон в `/home/user/alexliesenfeld/...`).

| Элемент исходника | Параметр | Использование |
|---|---|---|
| `device_width/depth/height = 150/150/50.5` | → 151/151/52 | заменено на MSI |
| `wall = 5`, `floor_thickness = 5` | сохранены | ТЗ п.13: 4–5 мм |
| `floor_support_width = 20`, `floor_channel_width = 20` | сохранены | 4 рельса × 20 мм, каналы 20 мм спереди-назад |
| `floor_support_front/rear_setback = 20` | сохранены | каналы открыты у переднего и заднего края |
| `width_clearance = 10.5` | → 10 | боковой зазор |
| `back_stopper_*` (2 стопора на внутренних рельсах, 3×10 мм, R2) | сохранены | центральный канал свободен |
| `rounded_step_side_wall` (ступенчатый профиль стенки, R5) | сохранён | высокая передняя часть → низкая направляющая |
| `holder_z = fan_center_z − 5 − device_height/2` (устройство по оси вентилятора) | сохранён принцип | ось 140-мм вентилятора z=75 → дно MSI z=49 |
| `front_panel`, `rack_hole`, `fan_cutouts` (2×80), rack-ears | **удалены** | ТЗ п.3 |

Новое: передние стойки 10 мм под heat-set M3 (фланец воздуховода), пазы M4 в
дне (крепление к корпусу), пазы под ремень, гнёзда датчиков, анкеры стяжек.

Лицензия исходника — CC BY-NC 4.0: производная модель некоммерческая,
авторство Alexander Liesenfeld указано в README.

## 3. [АРХИВ v1] Корпус 4U — по двум фотографиям

Интерпретация фото (подтвердить замерами, п.1–12 чек-листа):

**Фото 1 (фронт).** Слева ~⅓ ширины фасада — щелевая решётка (2 группы ×
~5 рядов коротких щелей; оценочно живое сечение 35–40 %). Справа — запираемая
дверца с тремя треугольными окнами; за окнами тёмный материал — **сетка или
тонированный пластик, не ясно** (п.11). Сверху виден снятый верх: внутри у
задней стенки два 80-мм вентилятора.

**Фото 2 (вид сверху, перед слева, PCI-слоты справа-сверху).** Ориентация:
верхний край фото = правая стенка корпуса (если смотреть спереди), т.к.
PCI-слоты и задние 80-мм вентиляторы в ATX-компоновке стоят справа-сзади,
а проём БП — слева-сзади.

| Что видно | Где | Решение |
|---|-----|---|
| Вертикальная HDD-корзина с перфорацией (3 колонки отверстий, 6 рядов), во всю высоту | перед-право, за дверцей; оценочно ~230 мм ширины × ~110 мм глубины | **демонтировать** — занимает место вентилятора и воздуховода трака 2 |
| Перфорированный кронштейн 3×3 отверстия (плата под диски/вентиляторы) | перед-лево, за щелевой решёткой | **демонтировать** — место вентилятора трака 1 |
| Корзина/стойка в переднем левом углу с шестигранной стойкой | перед-лево, у ручки | убрать, если выступает выше 5 мм над дном |
| ATX-блок питания (чёрный блок в чехле) + жгуты Molex/SATA/24-pin, не закреплён | центр | **убрать из корпуса**: штатный проём БП (зад-лево) пересекается с устройством и выхлопной зоной трака 1 при глубине корпуса < ~560 мм. Для питания вентиляторов достаточно 12 В / 2 А |
| Плата-хаб вентиляторов (4-pin, Molex-вход) | у задних вентиляторов | оставить, использовать для задних 80-мм |
| 2 × 80 мм вентилятора на задней стенке | зад, у PCI-слотов (справа) | **оставить как вытяжку** — это «опциональный rear exhaust» из ТЗ п.11, уже есть |
| 7 PCI-слотов с заглушками | зад-право | заглушки снять → проёмы для кабелей MSI № 2 (сеть, USB-C, питание) и дополнительный выход воздуха |
| Проём под ATX-БП в задней стенке (~150×86) | зад-лево | после удаления БП — проём для кабелей MSI № 1 и выхлоп; закрыть печатной/сетчатой заглушкой с вырезами под кабели |
| Пропорции корпуса | глубина ≈ 0.9 ширины по фото → ~400–450 мм | **TO_MEASURE**; модель рассчитана на 441 мм при параметрах по умолчанию и на ~400 мм в «компактном» наборе (см. 02_layout.md §6) |

Внешние блоки питания MSI (240 Вт USB-C, ~170×70×30 каждый): внутри корпуса
места для них рядом с траками нет (по 26 мм с каждого бока при ширине 430).
Варианты: снаружи на полке стойки (основной), либо в задних углах корпуса,
если глубина ≥ 500 мм — вне прямого выхлопа.

## 4. Опыт сообщества (NVIDIA Developer Forums, Printables)

Темы «Dual Spark Ducted Cooling Cage», «My DGX Spark extra cooling solution»,
«DIY DGX Spark Cooling System for 2x Cluster» (прямой доступ к форуму из
сессии закрыт; по сниппетам поиска):

* подача воздуха **в переднюю решётку** одним 120/140-мм вентилятором на малых
  оборотах снижает GPU-температуру под нагрузкой с ~85 °C до 61–73 °C
  (разные сборки, −5…−20 °C);
* в сборке «dual node» общий duct с одним вентилятором на две ноды давал
  разные температуры нод → подтверждает требование ТЗ п.8: **два независимых
  канала**;
* проблема «metal casing heat soak»: корпус устройства нагревается, холодный
  обдув снаружи корпуса (а не только в решётку) тоже помогает → наша схема
  не герметизирует устройство, часть потока уходит по каналам под днище и
  вдоль боков;
* у референса DGX Spark поток спереди назад; у MSI, по заявлению MSI, также
  спереди назад с боковыми выходами.

## 5. Итог этапа 1 — принятая компоновка (v2)

Два трака рядом в одном слое, оба устройства «сотами вперёд», на общей
base_plate за панелью ФП-5:

```
[решётка ARCTIC 140] → [ФП-5] → [P14 Pro PST 27] → [duct 120: plenum 50 + nozzle 70]
    → [EPDM 5] → [MSI 151] → [свободный выхлоп ≥ 90] → горячая зона шкафа → 1U вытяжка
```

Ширина пары 377 мм на плите `rack_opening_w − 6` (TO_MEASURE); высота по
вентилятору 148 мм над полкой — в 5U-панели 221.5 при `shelf_top_z` 12…53.5.
Длина модуля 393 мм — в шкафу 600 мм. См. `02_layout.md`.

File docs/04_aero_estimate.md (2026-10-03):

# Инженерная оценка аэродинамики (без CFD) — v2, Arctic P14 Pro PST

Числа — оценка первого порядка для выбора геометрии и рабочей точки. Расход
через EdgeXpert задают его собственные вентиляторы; внешний 140-мм вентилятор
создаёт подпор на входе, исключает рециркуляцию и продувает каналы под днищем.

## 1. Требуемый расход по теплу

P = 200 Вт на устройство (MSI: устойчиво > 200 Вт; TDP SoC 140 Вт).
Воздух 35 °C: ρ ≈ 1.15 кг/м³, cp ≈ 1006 Дж/(кг·К). Q = P / (ρ·cp·ΔT):

| ΔT через устройство | Q на тракт |
|----|----|
| 10 К | 62 м³/ч (37 CFM) |
| 15 К | 41 м³/ч (24 CFM) |
| 20 К | 31 м³/ч (18 CFM) |

Рабочий диапазон тракта: **40–60 м³/ч**. На модуль: 80–125 м³/ч; это и должен
вытягивать 1U вентиляторный модуль сверху (типично 2–4 × 120 мм ≈ 150–300 м³/ч
— достаточно; проверить по его паспорту).

## 2. Характеристика Arctic P14 Pro PST [SRC: Arctic]

| Параметр | Значение |
|---|---|
| Обороты | 400–2500 об/мин (PWM) |
| Qmax | 186 м³/ч (109 CFM) |
| Pmax | 5.2 мм H₂O (51 Па) |
| Ток | 0.35 А при 12 В |
| Особенность | **0 об/мин при PWM < 5 %** → минимум PWM в контроллере ≥ 15–20 %, автостоп запрещён |

Законы подобия (Q ~ n, P ~ n²) от точки 2500 об/мин:

| об/мин | PWM, % (оценка, линейно 400→2500) | Q свободн., м³/ч | Pmax, Па |
|---|---|---|---|
| 400 | 0…5 (мин. вращения) | 30 | 1.3 |
| 600 | ~15 | 45 | 2.9 |
| 750 | ~20 | 56 | 4.6 |
| 900 | ~27 | 67 | 6.6 |
| 1200 | ~40 | 89 | 11.7 |
| 2500 | 100 | 186 | 51 |

Рабочая точка при сопротивлении тракта ~10–20 Па (п.4): расход 40–60 м³/ч
достигается при **≈ 700–900 об/мин** (запас по напору ~2× против P14 PWM PST
из v1). Нижняя уставка контроллера 20 % (~750 об/мин) уже даёт ≈ 45–55 м³/ч —
дежурный режим без регулирования может оказаться достаточным; верх 100 %
только как fail-safe.

## 3. Сечения и скорости (Q = 60 м³/ч = 0.0167 м³/с)

| Сечение | Размер | Площадь | Скорость |
|---|---|---|---|
| Кольцо лопастей (D ≈ 132, ступица 45) | — | 121 см² | 1.4 м/с |
| Вырез панели Ø138 + решётка (живое ~85 %) | — | 127 см² | 1.3 м/с |
| Вход воздуховода | 135 × 135, R12 | 181 см² | 0.9 м/с |
| Выход воздуховода | 145 × 57, R6 | 82 см² | 2.0 м/с |
| Соты MSI (оценка 145 × 46, живое 55 %) | — | ~37 см² | ~4.5 м/с |

Сопло: по высоте 135 → 57 (сужение), по ширине 135 → 145 (расширение 5 мм на
сторону, полуугол 4.5° на 64 мм — безотрывно). Отношение площадей 2.2.
Потери конфузора ζ ≈ 0.05–0.1 по скорости выхода → ~0.2 Па, пренебрежимо.

## 4. Баланс давлений на тракт при 60 м³/ч

| Элемент | Δp |
|---|---|
| Решётка ARCTIC 140 (проволочная, живое ~85 %) | 1–2 Па |
| Вырез панели Ø138 (острая кромка, ζ ≈ 0.5 по 1.3 м/с) | ~0.5 Па |
| Воздуховод | < 1 Па |
| Соты MSI | 6–10 Па |
| Утечки через EPDM/байпас | снижают подпор |
| **Внутри модуля** | **~10–14 Па** |
| Стеклянная дверь + щели шкафа (вход в холодную зону) | **главная неизвестная: 0…30+ Па** |
| Зазор под/вокруг двери (типично 2 × 10 мм × 600 мм ≈ 120 см² на 125 м³/ч) | ~3–6 Па при чистых щелях |

При глухой двери без перфорации холодная зона питается только щелями двери; на
125 м³/ч суммарно это уже 3–6 Па и, главное, подсос тёплого воздуха из горячей
зоны через любые неуплотнённые щели между стойками и боковинами. Поэтому
уплотнение (`07_rack_layout.md` §2) важнее запаса по напору вентилятора.

## 5. Главная неизвестная — стеклянная дверь

Измерить после сборки: T_cold (у решётки) − T_room при полной нагрузке.

| Результат | Действие |
|---|---|
| ΔT ≤ 2 °C | дверь не ограничивает, ничего не менять |
| 2–5 °C | уплотнить щели стоек/боковин, проверить заглушки |
| > 5 °C | дверь ограничивает: перфорация/сетка в нижней трети, приоткрытая дверь или 120-мм вдув в цоколе |

## 6. Мёртвая зона ступицы и пленум

Ступица 45 мм — 13 % площади; зона рециркуляции 25–45 мм за ступицей; пленум
50 мм + ускорение в конфузоре выравнивают профиль. Лопатки выключены
(`guide_vanes = 0`). Смещение оси выхода вниз на 5.5 мм (заход под днище) —
несущественно.

## 7. Байпас под устройством — предмет испытаний

Выход воздуховода заходит на 8 мм ниже дна MSI; каналы между рельсами (17 мм ×
44 мм × 4 шт. + боковые) открыты назад → часть потока (оценочно 15–25 % при
открытых каналах) уходит под устройством мимо сот. Польза: обдув днища
(SSD/VRM под «elevated footpads», нижняя щелевая решётка). Вред: меньше подпора
на сотах.

Заслонка `bypass_block` (гребёнка у задних торцов рельсов):

| bypass_block | Что происходит | Когда |
|---|---|---|
| 0 (нет) | каналы открыты, максимум обдува днища, минимум подпора | если T_out низкая, а дно горячее |
| 0.5 | каналы перекрыты наполовину | стартовый вариант |
| 1.0 | каналы — тупиковый пленум; воздух под днищем только через нижнюю решётку MSI | если нижняя решётка — вход (TO_MEASURE п.12) |

Критерий: минимальная T_out при равном PWM; измерять по 15 мин на каждой
заслонке при одинаковой нагрузке.

## 8. Прочие проблемные места

1. Вибрация сэндвича панель–вентилятор: нейлоновые шайбы, не перетягивать;
   при гуле — резиновые проставки 2 мм между вентилятором и панелью (учесть в
   длине болта).
2. Свист решётки: ARCTIC проволочная, расстояние лопасть–решётка = panel_t +
   ~3 мм; при свисте — проставка 5 мм.
3. Рециркуляция выхлопа MSI в холодную зону — только через неуплотнённые щели;
   см. §4–5.

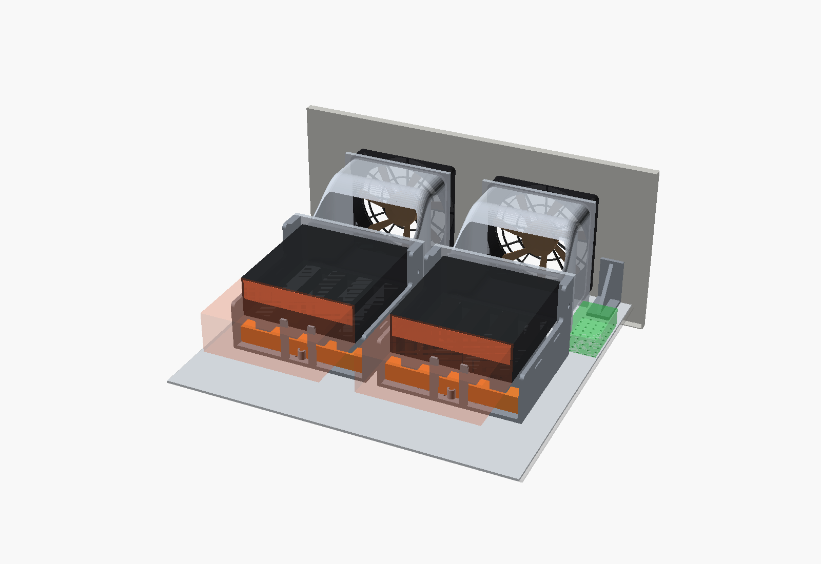
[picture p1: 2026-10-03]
docs/renders/module_PREVIEW.png

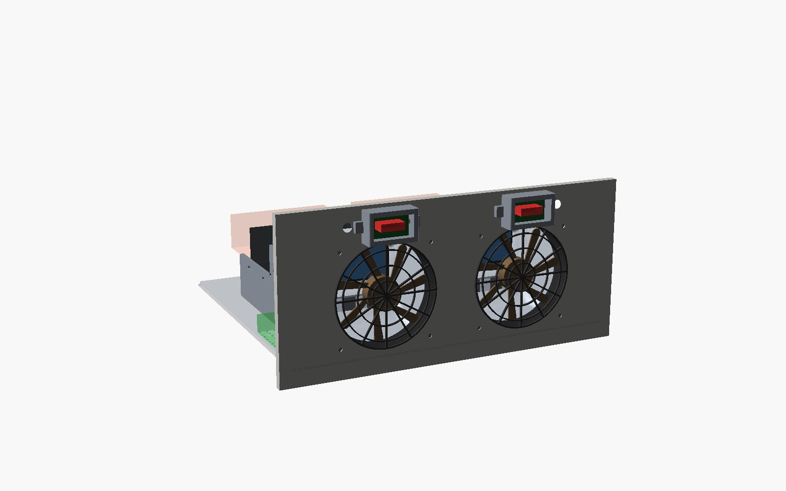
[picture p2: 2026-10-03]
docs/renders/module_front_PREVIEW.png

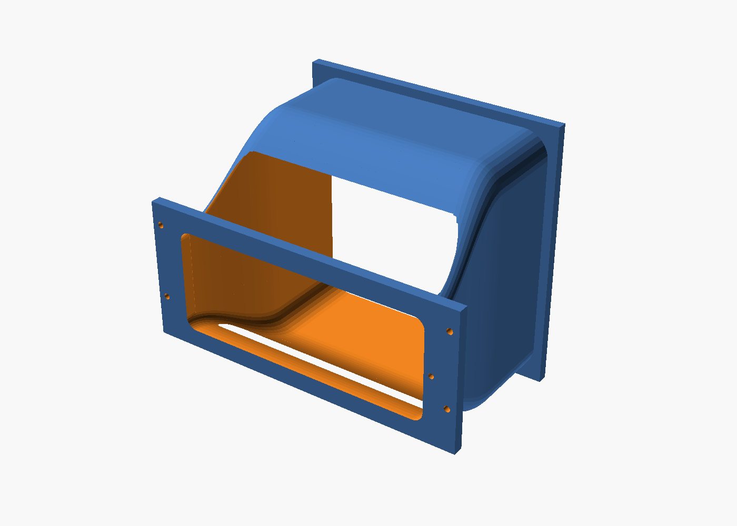
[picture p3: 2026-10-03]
docs/renders/duct_PREVIEW.png

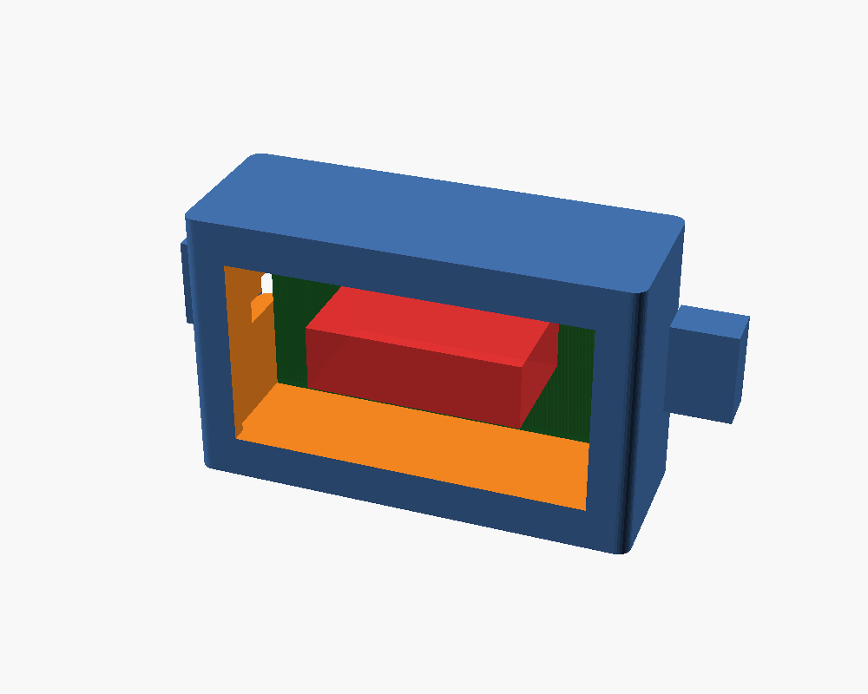
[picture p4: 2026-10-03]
docs/renders/ctrl_bezel_PREVIEW.png

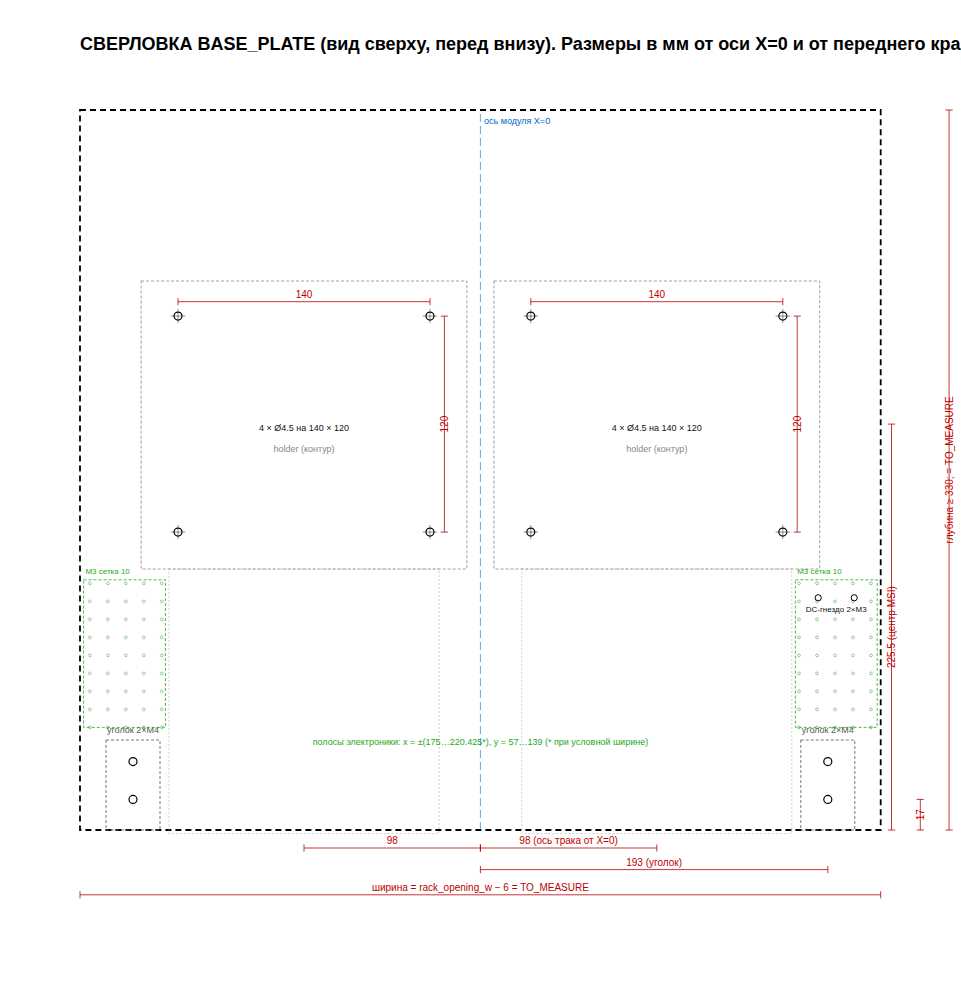
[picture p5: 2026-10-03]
docs/drawings/base_plate.png

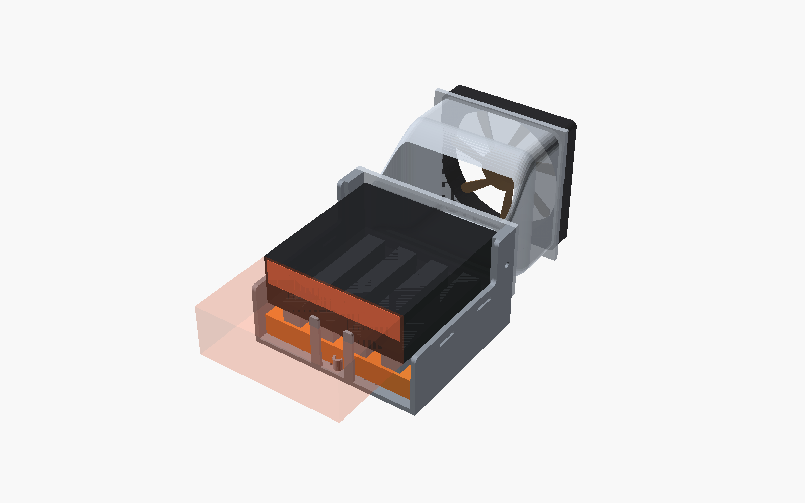
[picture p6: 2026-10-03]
docs/renders/track_PREVIEW.png

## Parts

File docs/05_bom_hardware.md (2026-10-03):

# Спецификация (на один 5U-модуль = 2 трака)

## Печатные детали (PETG прототип / ASA финал)

| Деталь | Файл (`stl/`) | Кол-во | Ориентация | Настройки |
|---|---|---|---|---|
| Holder | `edgexpert_holder[_PREVIEW].stl` | 2 | дном на стол | 4 периметра, инфилл 15–20 %, без поддержек |
| Заслонка байпаса | `bypass_baffle_050/_100[_PREVIEW].stl` | 2 × (0.5 и 1.0) для испытаний | плашмя | 3 периметра |
| Воздуховод цельный | `duct[_PREVIEW].stl` | 2 | выходным фланцем на стол | 3 периметра при сопле 0.4; поддержка под входной фланец |
| Воздуховод, часть A/B | `duct_part_a_plenum`, `duct_part_b_nozzle` | 2+2* | фланцами на стол | *только при `duct_split=true` |
| Уголок panel↔base_plate | `panel_bracket[_PREVIEW].stl` | 2 | на боковую грань (полки вверх) или вертикальной полкой на стол | 5 периметров, инфилл 30 % |
| Стойка DC-гнезда | `dc_jack_bracket[_PREVIEW].stl` | 1 | полкой на стол | — |
| Рамка контроллера | `ctrl_bezel.stl` (экспорт только при известных ctrl_w/h/d) | 2 | лицевой стенкой на стол | 3 периметра; без поддержек |
| Рамка вентилятора (стенд) | `fan_bracket_bench_OPTIONAL[_PREVIEW].stl` | 0–2 | плашмя | только для настольных испытаний |

Габариты: holder 181×160×109; duct 181×150×120; уголок 30×50×60. Всё ≤ 250×250.

## Покупные части

| Позиция | Кол-во | Примечание |
|---|---|---|
| Фронтальная панель ЦМО ФП-5 (5U, 482.6×221.5, сталь, RAL 7035) | 1 | два выреза Ø138 + 8 пазов M4 по `docs/drawings/panel_fp5.svg` (резать после замера `shelf_top_z`) |
| Лист алюминия 3 мм, (rack_opening_w − 6) × ≥ 330 | 1 | сверловка по `docs/drawings/base_plate.svg` |
| Вентилятор Arctic P14 Pro PST (ACFAN00314A), 140×140×27, 4-pin PWM, 0.35 А | 2 | 400–2500 об/мин, 186 м³/ч, 5.2 мм H₂O |
| Решётка ARCTIC Fan Grill 140 | 2 | снаружи панели, под болты сэндвича |
| PWM-термоконтроллер 12 В, 4-pin, 25 кГц, с дисплеем и датчиком NTC | 2 | **минимум PWM ≥ 15–20 %, без автостопа**; стоит в рамке на лицевой стороне ФП-5; датчик — в гнездо T_out |
| Резиновая втулка (grommet) под отверстие Ø12, лист 1–2 мм | 2 | кабели вентилятора, 12 В и датчика через панель |
| WAGO 221-413 | 2 | «+» и «−» 12 В |
| Адаптер 12 В / 2 А с штекером 5.5×2.5 | 1 | 2 × 0.35 А + контроллеры ≪ 2 А |
| Панельное DC-гнездо 5.5×2.5 | 1 | на стойке `dc_jack_bracket`; проверить штекер |
| EPDM самоклеящийся 10×5 | 1 м | по периметру выходного фланца (≈0.4 м на трак) |
| Датчик DS18B20/NTC (резерв, для T_in и ESP32) | 2–4 | гнёзда Ø6.2 |
| Удлинитель 4-pin PWM 30 см | 2 | |
| Ремень-липучка 20 мм | 2 × 0.5 м | пазы holder'а |
| Стяжки 2.5 мм | 20 | анкеры holder'а |
| Заглушки ЦМО ФП-1/2/5 глухие (не «.4») | по раскладке | `07_rack_layout.md` |
| Щёточный уплотнитель / поролон для боковых щелей | по высоте шкафа ×2 | |

## Крепёж

Длина болтов сэндвича: `L = grille_t + panel_t + 27 + 6 (фланец с гайкой внутри) + 2…3 мм выступа`.

| panel_t | стек (решётка 3) | болт |
|---|---|---|
| 1.0 | 37.0 | M4×40 |
| 1.2 | 37.2 | M4×40 |
| 1.5 | 37.5 | M4×40 |
| 2.0 | 38.0 | M4×40 (выступ 2 мм — минимум; при решётке > 4 мм → M4×45) |

| Позиция | Размер | Кол-во | Где |
|---|---|---|-----|
| Болт DIN 912/7985 | M4×40 (см. таблицу) | 8 | сэндвич решётка–панель–вентилятор–входной фланец |
| Гайка DIN 934 | M4 | 8 | гнёзда во входном фланце воздуховода (7 AF × 3.2) |
| Шайба нейлоновая | M4 | 8 | под головки сэндвича (виброразвязка, не затягивать «намертво») |
| Heat-set вставка | M3, OD 4.0–4.6 × 5–6 | 8 | передние стойки holder'ов |
| Винт | M3×10 | 8 | выходной фланец → holder |
| Винт + шайба | M4×8 | 8 | holder → base_plate (пазы 4.5×10, цековка Ø9) |
| Гайка + шайба | M4 | 8 | под base_plate (или rivnut M4 в плите) |
| Винт + шайба | M4×10 | 4 | уголки → base_plate |
| Гайка | M4 | 4 | под base_plate |
| Болт + шайба + гайка | M4×12 | 4 | уголки → панель (отверстия в панели вне решёток; гайки снаружи) |
| Винт | M3×8 | 2 | стойка DC-гнезда (гайки под плитой или rivnut M3) |
| Heat-set вставка + винт M3×8 | M3 | 4 + 4 | лапки рамок контроллеров; винты заходят сзади панели через Ø3.4 |
| Винт в клетевую гайку | M6×16 + клетевые гайки M6 | 4 | ФП-5 → передние стойки (штатные) |
| (опция) Heat-set M3 + M3×8 | — | 8 | фланец разреза воздуховода при `duct_split` |

Не использовать саморезы в пластик в местах многократной разборки: все
разборные стыки — гайки/вставки.

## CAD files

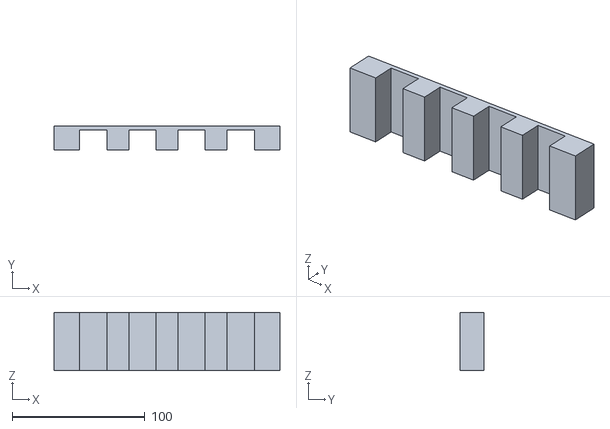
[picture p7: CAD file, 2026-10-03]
stl/bypass_baffle_100_PREVIEW.stl
170.4 x 18.0 x 44.0

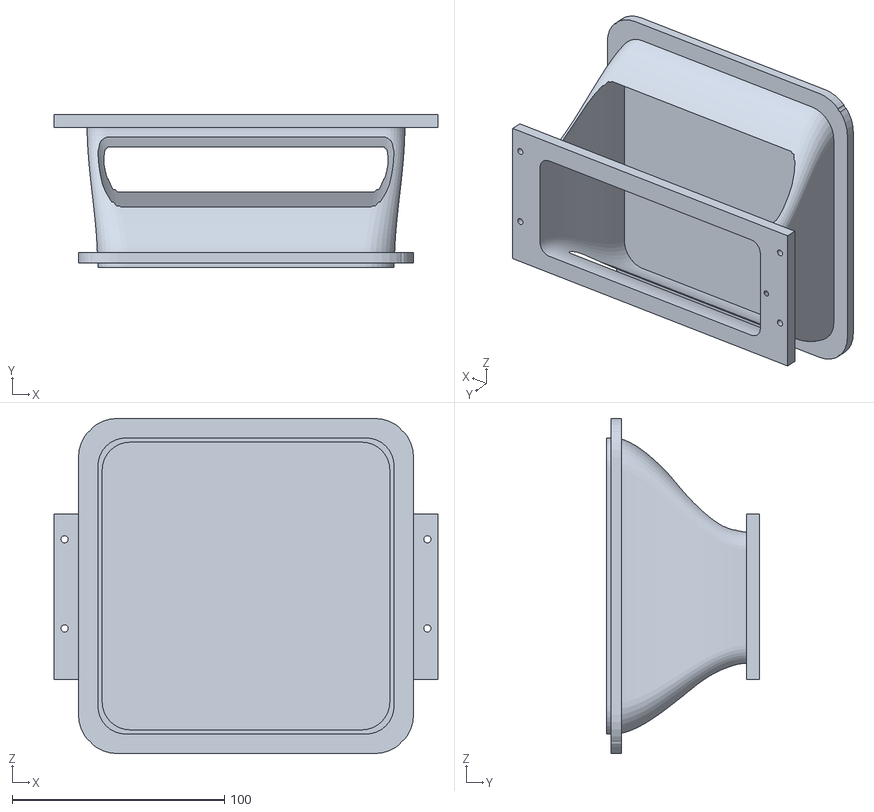
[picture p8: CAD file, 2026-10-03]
stl/duct_part_b_nozzle_PREVIEW.stl
181.0 x 72.0 x 158.0

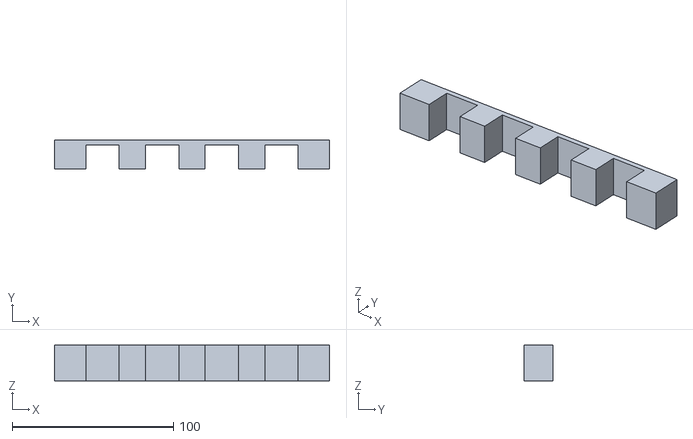
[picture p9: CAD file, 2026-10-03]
stl/bypass_baffle_050_PREVIEW.stl
170.4 x 18.0 x 22.0

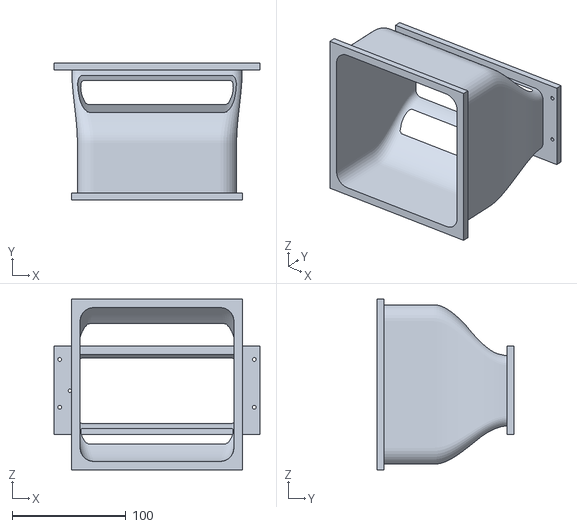
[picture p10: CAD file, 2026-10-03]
stl/duct_PREVIEW.stl
181.0 x 120.0 x 150.0

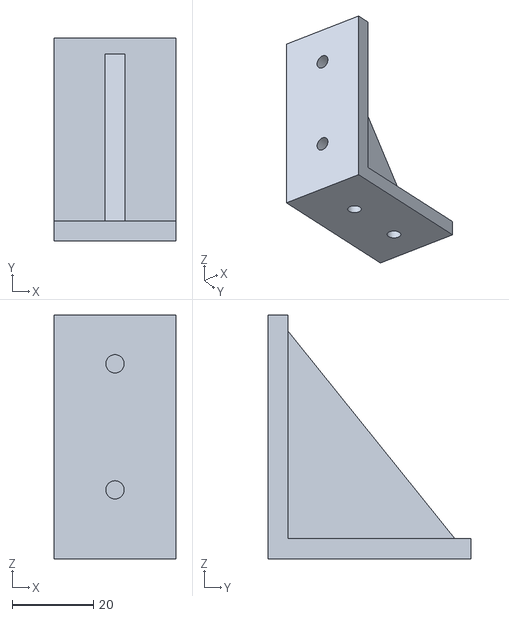
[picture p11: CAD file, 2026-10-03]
stl/panel_bracket_PREVIEW.stl
30.0 x 50.0 x 60.0

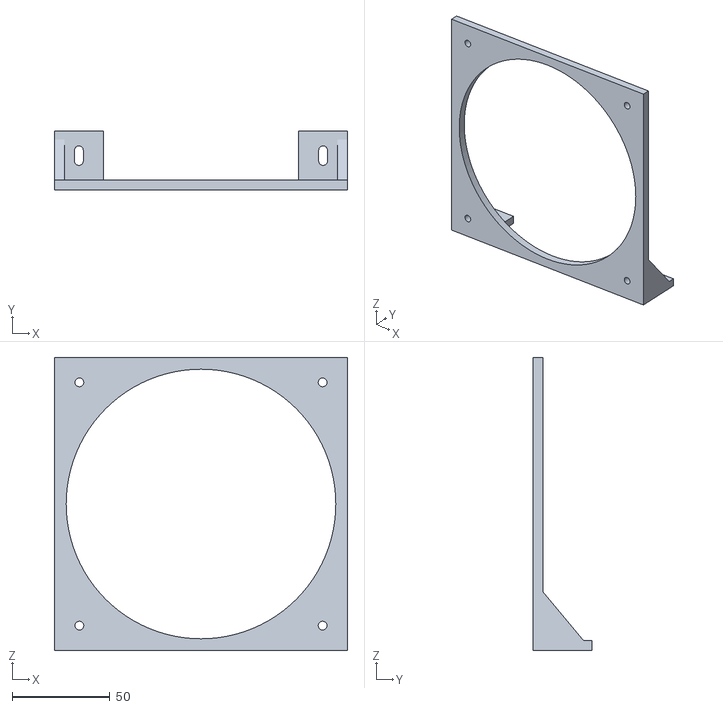
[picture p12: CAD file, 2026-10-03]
stl/fan_bracket_bench_OPTIONAL_PREVIEW.stl
150.0 x 30.0 x 150.0

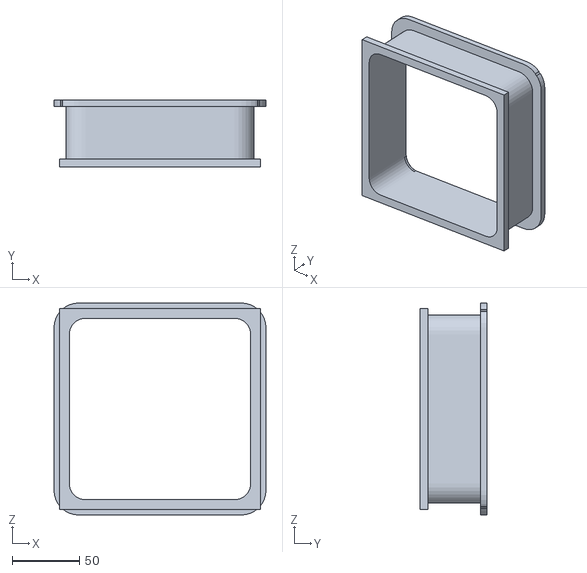
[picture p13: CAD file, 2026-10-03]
stl/duct_part_a_plenum_PREVIEW.stl
158.0 x 50.0 x 158.0

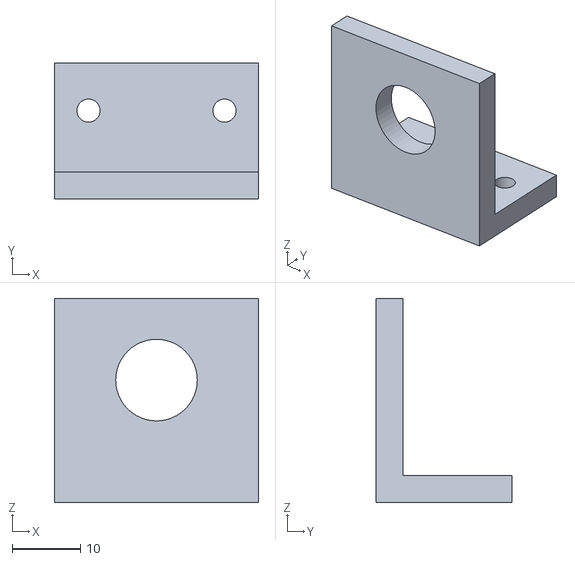
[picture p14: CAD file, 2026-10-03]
stl/dc_jack_bracket_PREVIEW.stl
30.0 x 20.0 x 30.0

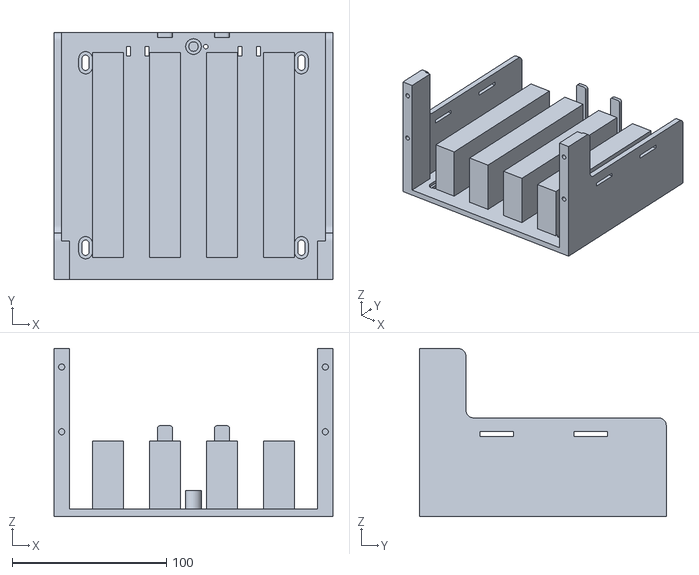
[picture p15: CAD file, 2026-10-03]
stl/edgexpert_holder_PREVIEW.stl
181.0 x 160.0 x 109.0

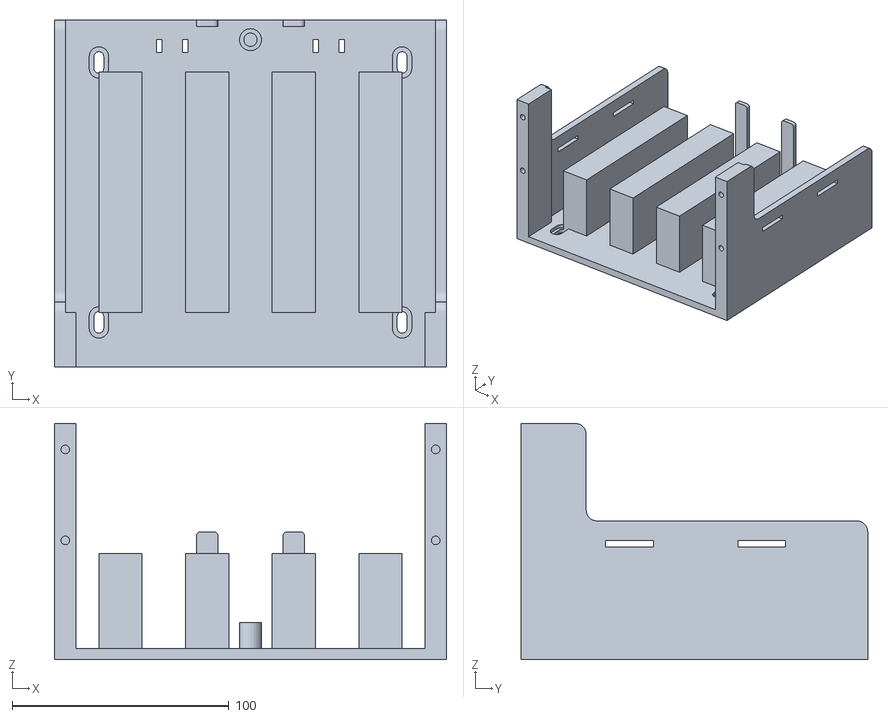
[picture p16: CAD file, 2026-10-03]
stl/edgexpert_holder.stl
181.0 x 160.0 x 109.0

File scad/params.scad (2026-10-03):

/*
 * dual-spark-4u — общие параметры проекта (v2: 5U-модуль в 18U шкафу).
 *
 * ВСЕ размеры в миллиметрах. Оси модуля:
 *   X = ширина, 0 = ось симметрии модуля (= ось панели ФП-5 и base_plate)
 *   Y = глубина, 0 = ЗАДНЯЯ плоскость панели ФП-5 (к ней прижат вентилятор);
 *       панель и решётка лежат в y < 0, тракт растёт в +Y
 *   Z = высота, 0 = верх полки шкафа (= низ base_plate)
 *
 * Статус параметра:
 *   [SRC]  — есть источник (см. docs/01_analysis.md, docs/TZ.md)
 *   [ASSM] — инженерное допущение, обосновано в документации
 *   TO_MEASURE — реальное значение неизвестно → значение undef.
 *                Детали, которым оно не нужно, рендерятся; сборка,
 *                base_plate и вертикальная разметка панели — нет
 *                (assert), пока параметр не измерен и не внесён.
 *
 * Файл подключается через include <params.scad> во всех остальных .scad.
 */

// ---------------------------------------------------------------------------
// 1. УСТРОЙСТВО: MSI EdgeXpert AI (MS-C931), класс DGX Spark / GB10
// ---------------------------------------------------------------------------
device_width  = 151;   // [SRC] карточки MS-C931: 151 x 151 x 52
device_depth  = 151;   // [SRC]
device_height = 52;    // [SRC] (с ножками или без — TO_MEASURE п.13)
device_mass_kg = 1.2;  // [SRC]

// Зона сот на передней грани: внешний габарит минус рамка. TO_MEASURE п.15.
device_intake_margin_x   = 3;  // [ASSM]
device_intake_margin_top = 3;  // [ASSM]
device_intake_margin_bot = 3;  // [ASSM]

// Ножки: 4 круглые по углам (msi.png в dgx-spark-printables). TO_MEASURE п.14.
device_foot_dia    = 16;  // [ASSM]
device_foot_inset  = 20;  // [ASSM] центр ножки от бокового и переднего/заднего края
device_foot_height = 4;   // [ASSM] «elevated stacking footpads»

// Нижняя щелевая решётка у переднего края по центру (msi.png). TO_MEASURE п.16.
device_bottom_vent_w = 40;  // [ASSM]
device_bottom_vent_d = 55;  // [ASSM]
device_bottom_vent_front_offset = 12; // [ASSM]

// ---------------------------------------------------------------------------
// 2. ВЕНТИЛЯТОР: Arctic P14 Pro PST (ACFAN00314A)  [SRC: Arctic datasheet]
// ---------------------------------------------------------------------------
fan_model      = "Arctic P14 Pro PST";
fan_size       = 140;
fan_thickness  = 27;     // [SRC] 140 x 140 x 27
fan_mass_g     = 242;    // [SRC]
fan_hole_pitch = 124.5;  // [SRC] стандарт; у Arctic встречается «125» → пазы ±0.5; TO_MEASURE п.16
fan_hole_tol   = 0.5;    // допуск межцентрового → отверстия выполнены пазами ±tol
fan_hole_dia   = 4.5;    // под болт M4
fan_open_dia   = 138;    // [ASSM] вырез в панели и проём фланца (без решётки)
fan_hub_dia    = 45;     // [ASSM] для оценки мёртвой зоны
fan_rpm_min    = 400;    // [SRC]
fan_rpm_max    = 2500;   // [SRC]
fan_q_max_m3h  = 186;    // [SRC]
fan_p_max_mmH2O = 5.2;   // [SRC]
fan_i_a        = 0.35;   // [SRC]
pwm_min_percent = 20;    // [SRC] P14 Pro: 0 об/мин при PWM < 5 % → контроллер не ниже 15–20 %, автостоп запрещён

grille_t       = 3;      // [ASSM] ARCTIC Fan Grill 140, проволочная; TO_MEASURE п.17

// ---------------------------------------------------------------------------
// 3. ШКАФ 18U И ПОЛКА — ВСЁ TO_MEASURE (undef)
// ---------------------------------------------------------------------------
rack_opening_w     = undef; // TO_MEASURE п.1  проём между внутренними гранями передних стоек (EIA-310 номинал 450.85)
shelf_top_z        = undef; // TO_MEASURE п.2  верх полки относительно НИЖНЕГО края ФП-5 (вверх +)
shelf_depth        = undef; // TO_MEASURE п.3  глубина полки
panel_t            = undef; // TO_MEASURE п.4  толщина листа ФП-5
panel_hole_pitch_v = undef; // TO_MEASURE п.5  вертикальный шаг крепёжных отверстий в ушах ФП-5
rack_depth         = 600;   // [SRC] глубина шкафа (ТЗ v2 п.1)

// ---------------------------------------------------------------------------
// 4. ФРОНТАЛЬНАЯ ПАНЕЛЬ ЦМО ФП-5 (сталь, RAL 7035)
// ---------------------------------------------------------------------------
panel_w        = 482.6;  // [SRC]
panel_h        = 221.5;  // [SRC]
panel_fold     = 10;     // [SRC] отбортовка внутрь (в −Y… т.е. назад, в модуль)
panel_edge_keepout = 15; // [SRC ТЗ v2] вырезы и фланцы не ближе 15 мм к краям панели
panel_color    = [0.78, 0.78, 0.76]; // RAL 7035 (визуально)

// ---------------------------------------------------------------------------
// 5. BASE PLATE (алюминий 3 мм) И УГОЛКИ
// ---------------------------------------------------------------------------
base_plate_t        = 3;    // [SRC ТЗ v2]
base_plate_side_gap = 3;    // [SRC ТЗ v2] ширина = rack_opening_w − 2×3
base_plate_depth_min = 330; // [SRC ТЗ v2] ≥ 330; фактическая = по полке (TO_MEASURE п.3)
base_plate_front_gap = 2;   // [ASSM] зазор от задней плоскости панели до переднего края плиты

bracket_w      = 30;   // [ASSM] ширина уголка panel↔base_plate
bracket_h      = 60;   // [ASSM] высота вертикальной полки (по панели)
bracket_d      = 50;   // [ASSM] глубина горизонтальной полки (по плите)
bracket_t      = 5;    // [ASSM] толщина полок
bracket_hole_d = 4.5;  // M4
bracket_x_from_center = 0; // 0 → автоматически: снаружи от фланца воздуховода + 5 мм

// ---------------------------------------------------------------------------
// 6. ТРАКТ: решётка → панель → вентилятор → воздуховод → holder → MSI → выхлоп
// ---------------------------------------------------------------------------
fan_axis_above_plate = 75;  // [SRC ТЗ v2] ось вентилятора = верх base_plate + 75

plenum_len   = 50;   // [ASSM] (ТЗ 40–80), включая входной фланец
nozzle_len   = 70;   // [ASSM] включая выходной фланец; duct = 120 (ТЗ 100–180)
duct_wall    = 2.4;  // [ASSM] (ТЗ 2–3)
duct_flange_t = 6;   // [ASSM]
duct_inlet_corner_r  = 12;
duct_outlet_corner_r = 6;
duct_slices  = 28;
duct_split   = false; // true → две части по границе plenum/nozzle
duct_tongue  = 2;
guide_vanes  = 0;     // 0 = нет; 2 = две вертикальные лопатки
vane_t       = 1.6;

gasket_t     = 5;    // [ASSM] EPDM между выходным фланцем и передней гранью MSI
outlet_under_device = 8;  // [ASSM] выход заходит ниже дна MSI (подача под ножки / к нижней решётке)
outlet_over_device  = 0;

rear_free_zone = 90;  // [SRC ТЗ v2] свободный выхлоп ≥ 90

// ---------------------------------------------------------------------------
// 7. HOLDER (адаптация spark-rack-10 holder)
// ---------------------------------------------------------------------------
holder_side_clearance = 10;
holder_rear_clearance = 1;
holder_wall      = 5;
holder_floor_t   = 5;
rail_w           = 20;
channel_w        = 20;         // используется, если rails_follow_feet = false
rails_follow_feet = true;      // внешние рельсы центрируются под ножками MSI (device_foot_inset)
rail_setback_margin = 3;       // рельс выходит за край ножки на столько мм
back_stop_t      = 3;
back_stop_w      = 10;
back_stop_extra_h = 10;
back_stop_r      = 2;
guide_wall_extra_h = 15;
front_post_len   = 25;
front_post_w     = 10;
step_r           = 5;

holder_mount_slot_l   = 10;    // пазы M4 → base_plate
holder_mount_slot_w   = 4.5;
holder_mount_cbore_d  = 9;
holder_mount_cbore_h  = 2.5;
holder_mount_pitch_x  = 140;   // [ASSM] сверловка base_plate делается ПО ЭТИМ значениям
holder_mount_pitch_y  = 120;   // [ASSM]

strap_slots      = true;
strap_slot_w     = 22;
strap_slot_h     = 3;

sensor_pocket_d  = 6.2;
sensor_pocket_h  = 10;

// Байпас под устройством: заслонка-гребёнка в каналах у заднего края.
// 0 = каналы открыты назад (нет заслонки), 1 = каналы перекрыты полностью.
bypass_block     = 0.5;        // [ASSM] предмет испытаний (docs/04 §7)
baffle_t         = 3;
baffle_finger_len = 15;
baffle_clearance = 0.3;

// ---------------------------------------------------------------------------
// 8. ЭЛЕКТРИКА (места на base_plate)
// ---------------------------------------------------------------------------
dc_jack_hole_d   = 12;   // [ASSM] панельное гнездо 5.5×2.5 (резьба M12/ø11.5) — TO_MEASURE п.18
// Полосы base_plate снаружи от воздуховодов, по одной на сторону: ТОЛЬКО WAGO 221-413
// (левая) и DC-гнездо (правая). Контроллеры — на лицевой стороне панели (секция 8a).
// Полосы лежат между уголком и выходным фланцем воздуховода; ширина зависит от rack_opening_w.
ctrl_zone_margin = 2;    // [ASSM] зазор зоны от воздуховода и от края плиты
ctrl_hole_grid   = 10;   // сетка M3 в зоне электроники
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

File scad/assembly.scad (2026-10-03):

/*
 * assembly.scad — 5U-модуль: панель ЦМО ФП-5 + 2 × (решётка, Arctic P14 Pro PST,
 * воздуховод, holder, MSI EdgeXpert) + base_plate + 2 уголка + зона электроники.
 *
 * part:
 *   module     — полная сборка (требует все TO_MEASURE: rack_checks)
 *   exploded   — сборка с раздвинутыми по Y деталями одного трака
 *   track      — один трак без панели/плиты (локальные координаты, без TO_MEASURE)
 *   printables — печатные детали одного трака, разложенные на плоскости
 *
 * Координаты модуля: x=0 — ось; y=0 — задняя плоскость панели; z=0 — верх полки.
 * Детали трака имеют локальный z от верха плиты → translate по hz0.
 */

include <params.scad>
use <lib/shapes.scad>
use <edgexpert_holder.scad>
use <duct.scad>
use <front_panel.scad>
use <base_plate.scad>
use <ctrl_bezel.scad>

part = "module"; // [module, exploded, track, printables]
explode_gap = 60;
show_devices = true;
show_fans = true;
show_ducts = true;
show_panel = true;
show_grilles = true;
show_baffles = true;
show_bezels = true;

geo_report();

// Один трак в локальных координатах (x=0 — левая грань holder'а, z=0 — верх плиты)
module track(explode = 0) {
    if (show_fans)
        translate([track_cx, y_fan_front - explode, fan_center_zl])
            fan_mockup(fan_size, fan_thickness, fan_hub_dia, fan_hole_pitch);
    if (show_ducts) color([0.75, 0.78, 0.82, 0.85]) duct_full();
    color([0.55, 0.58, 0.62]) translate([0, y_holder_front + explode, 0]) holder();
    if (show_baffles) color([0.9, 0.5, 0.2]) translate([0, y_holder_front + explode, 0]) baffle();
    if (show_devices)
        translate([device_x0, y_device_front + 2 * explode, device_base_zl])
            device_mockup(device_width, device_depth, device_height,
                          device_foot_dia, device_foot_inset, device_foot_height,
                          device_bottom_vent_w, device_bottom_vent_d, device_bottom_vent_front_offset,
                          device_intake_margin_x, device_intake_margin_top, device_intake_margin_bot);
    %translate([device_x0, y_device_rear, device_base_zl])
        color([1, 0.4, 0.2, 0.15]) cube([device_width, rear_free_zone, device_height]);
}

module grille_mockup(cx) {
    // проволочная решётка ARCTIC 140 перед панелью (условно — кольцо + спицы)
    color([0.2, 0.2, 0.2])
    translate([cx, -panel_t - grille_t, fan_center_z]) rotate([-90, 0, 0]) {
        difference() { cylinder(h = grille_t, d = fan_size, $fn = 96); translate([0, 0, -1]) cylinder(h = grille_t + 2, d = fan_size - 4, $fn = 96); }
        for (a = [0 : 30 : 150]) rotate([0, 0, a]) translate([-fan_size / 2, -1, 0]) cube([fan_size, 2, grille_t]);
        for (d = [40, 80, 120]) difference() { cylinder(h = grille_t, d = d, $fn = 64); translate([0, 0, -1]) cylinder(h = grille_t + 2, d = d - 3, $fn = 64); }
    }
}

module bezels() {
    // рамки контроллеров на лицевой стороне панели, над каждым вентилятором
    for (cx = fan_cx_from_center)
        translate([cx - bezel_w / 2, -panel_t, fan_center_z + fan_size / 2 + bezel_fan_clearance])
            mirror([0, 1, 0]) { color([0.55, 0.58, 0.62]) bezel(); ctrl_mockup(); }
}

module electronics_zone() {
    // по одной полосе на сторону: слева WAGO 221-413, справа DC-гнездо (контроллеры — на панели)
    for (sx = [-1, 1])
        %color([0.2, 0.8, 0.3, 0.35])
            translate([sx > 0 ? ctrl_zone_x_in : -(ctrl_zone_x_in + ctrl_zone_w), ctrl_zone_y0, base_plate_t])
                cube([ctrl_zone_w, ctrl_zone_d, 25]);
}

module module_assembly(explode = 0) {
    fit_report();
    if (show_panel) panel();
    if (show_grilles) for (cx = fan_cx_from_center) grille_mockup(cx);
    if (show_bezels) bezels();
    base_plate();
    for (sx = [-1, 1])
        translate([sx * bracket_cx - bracket_w / 2, base_plate_front_gap, base_plate_t])
            color([0.55, 0.58, 0.62]) panel_bracket();
    // стойка DC-гнезда: гнездо смотрит назад (штекер из горячей зоны шкафа)
    translate([ctrl_zone_x_in + ctrl_zone_w / 2 + 15, ctrl_zone_y1 - 10 + 7, base_plate_t]) rotate([0, 0, 180])
        color([0.55, 0.58, 0.62]) dc_jack_bracket();
    electronics_zone();
    for (cx = fan_cx_from_center)
        translate([cx - track_cx, 0, hz0]) track(cx > 0 ? explode : 0);
    // полка (условно) и ось шкафа
    %color([0.5, 0.5, 0.5, 0.2]) translate([-rack_opening_w / 2, -panel_t, -3]) cube([rack_opening_w, shelf_depth, 3]);
}

module printables() {
    holder();
    translate([0, holder_outer_w + 40, 0]) color([0.9, 0.5, 0.2]) baffle();
    translate([holder_outer_w + 30, -y_duct_in, 0]) duct_full();
    translate([holder_outer_w + 30, y_track_end + 40, 0]) panel_bracket();
    translate([holder_outer_w + 100, y_track_end + 40, 0]) dc_jack_bracket();
    translate([holder_outer_w + 160, y_track_end + 40, 0]) bezel();
}

if (part == "track") track(0);
else if (part == "exploded") module_assembly(explode_gap);
else if (part == "printables") printables();
else module_assembly(0);

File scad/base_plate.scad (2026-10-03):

/*
 * base_plate.scad — алюминиевая плита 3 мм 5U-модуля (покупной лист, сверловка
 * по чертежу docs/drawings/base_plate.svg) + печатные детали:
 *   part="panel_bracket"   — уголок panel↔base_plate (PETG/ASA, M4), 2 шт.
 *   part="dc_jack_bracket" — стойка под панельное гнездо 12 В 5.5×2.5, 1 шт.
 *   part="base_plate"      — сама плита с отверстиями (нужны rack_opening_w, shelf_depth)
 *   part="base_plate_2d"   — 2D-контур для чертежа
 *
 * Координаты модуля: x=0 — ось; y=0 — задняя плоскость панели; z=0 — верх полки.
 */

include <params.scad>
use <lib/shapes.scad>

part = "panel_bracket"; // [panel_bracket, dc_jack_bracket, base_plate, base_plate_2d]

// --- Сверловка плиты (x от оси, y от задней плоскости панели) --------------
// Holder'ы: 4 паза M4 каждый (holder_mount_pitch_x/y вокруг центра устройства)
function holder_holes(tx) = [for (sx = [-1, 1], sy = [-1, 1])
    [tx + sx * holder_mount_pitch_x / 2,
     y_device_front + device_depth / 2 + sy * holder_mount_pitch_y / 2]];
track_cxs = fan_cx_from_center;             // ±98 — оси траков
holder_hole_list = concat(holder_holes(track_cxs[0]), holder_holes(track_cxs[1]));
// Уголки: 2 отверстия M4 в горизонтальной полке каждого
bracket_hole_list = [for (sx = [-1, 1], k = [0, 1])
    [sx * bracket_cx, base_plate_y0 + bracket_t + 12 + k * (bracket_d - bracket_t - 24)]];
// Полосы электроники: две полосы (x = ±(ctrl_zone_x_in … +ctrl_zone_w)), сетка M3.
// Слева — WAGO 221-413 («+» и «−»), справа — стойка DC-гнезда. Контроллеры — на панели.
// (списки считаются только при известной ширине плиты — иначе undef-предупреждения)
ctrl_hole_list = known(ctrl_zone_w)
    ? [for (sx = [-1, 1], i = [0 : floor((ctrl_zone_w - 4) / ctrl_hole_grid)],
            j = [0 : floor(ctrl_zone_d / ctrl_hole_grid)])
        [sx * (ctrl_zone_x_in + 2 + i * ctrl_hole_grid), ctrl_zone_y0 + j * ctrl_hole_grid]]
    : [];
// Стойка DC-гнезда: 2 × M3 в правой полосе у её заднего края, гнездо смотрит назад
dc_bracket_pos = known(ctrl_zone_w) ? [ctrl_zone_x_in + ctrl_zone_w / 2, ctrl_zone_y1 - 10] : [0, 0];

module base_plate_2d() {
    rack_checks();
    difference() {
        translate([-base_plate_w / 2, base_plate_y0]) square([base_plate_w, base_plate_d]);
        for (h = holder_hole_list) translate(h) circle(d = m4_clear_d, $fn = 24);
        for (h = bracket_hole_list) translate(h) circle(d = m4_clear_d, $fn = 24);
        for (h = ctrl_hole_list) translate(h) circle(d = m3_clear_d, $fn = 16);
        for (sx = [-1, 1]) translate(dc_bracket_pos + [sx * 10, 0]) circle(d = m3_clear_d, $fn = 16);
    }
}

module base_plate() {
    color([0.82, 0.84, 0.86]) linear_extrude(height = base_plate_t) base_plate_2d();
}

// --- Уголок panel ↔ base_plate ---------------------------------------------
// Вертикальная полка — к панели (2 × M4 через панель, гайки снаружи под
// решёткой НЕ нужны: отверстия вне зоны решётки), горизонтальная — к плите.
// Локально: x — ширина уголка, y — глубина (0 = плоскость панели), z — высота (0 = верх плиты).
module panel_bracket() {
    difference() {
        union() {
            cube([bracket_w, bracket_t, bracket_h]);                  // вертикальная полка
            cube([bracket_w, bracket_d, bracket_t]);                  // горизонтальная полка
            // косынка
            translate([bracket_w / 2 - 2.5, 0, 0]) rotate([90, 0, 90]) linear_extrude(height = 5)
                polygon([[bracket_t, bracket_t], [bracket_d - 4, bracket_t], [bracket_t, bracket_h - 4]]);
        }
        for (z = [bracket_t + 12, bracket_h - 12])
            translate([bracket_w / 2, -0.01, z]) rotate([-90, 0, 0]) cylinder(h = bracket_t + 0.02, d = bracket_hole_d);
        for (y = [bracket_t + 12, bracket_d - 12])
            translate([bracket_w / 2, y, -0.01]) cylinder(h = bracket_t + 0.02, d = bracket_hole_d);
    }
}

// --- Стойка DC-гнезда -------------------------------------------------------
module dc_jack_bracket() {
    h = 30; w = 30; d = 20; t = 4;
    difference() {
        union() { cube([w, t, h]); cube([w, d, t]); }
        translate([w / 2, -0.01, h - 12]) rotate([-90, 0, 0]) cylinder(h = t + 0.02, d = dc_jack_hole_d);
        for (sx = [-1, 1]) translate([w / 2 + sx * 10, d - 7, -0.01]) cylinder(h = t + 0.02, d = m3_clear_d);
    }
}

if (part == "base_plate") base_plate();
else if (part == "base_plate_2d") base_plate_2d();
else if (part == "dc_jack_bracket") dc_jack_bracket();
else panel_bracket();

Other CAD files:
stl/fan_bracket.stl
scad/ctrl_bezel.scad
scad/duct.scad
scad/edgexpert_holder.scad
scad/fan_bracket.scad
scad/front_panel.scad

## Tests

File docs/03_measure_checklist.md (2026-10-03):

# Чек-лист замеров (TO_MEASURE)

Без пунктов 1–5 сборка модуля, base_plate и разметка панели **не собираются**
(`rack_checks()` → assert). Значения вносятся в `scad/params.scad` вместо `undef`,
затем `./scripts/export_all.sh` — суффикс `_PREVIEW` исчезает автоматически.

## A. Шкаф, полка, панель (рулетка/штангенциркуль, ±0.5 мм)

| № | Что измерить | Параметр | Как |
|---|---|---|-----|
| 1 | Проём между **внутренними** гранями передних стоек (не между отверстиями) | `rack_opening_w` | на уровне полки; EIA-310 номинал 450.85, реальный зависит от профиля стоек |
| 2 | Верх полки относительно **нижнего края ФП-5** в том положении, где панель будет прикручена | `shelf_top_z` | поставить полку и панель насухо; допустимо **12…53.5 мм**, иначе переставить полку на U-шаг или изменить `fan_axis_above_plate` |
| 3 | Глубина полки (несущая часть) | `shelf_depth` | нужно ≥ 330, лучше ≥ 365 (модуль 393 от панели, свес до 30 допустим) |
| 4 | Толщина листа ФП-5 | `panel_t` | штангенциркулем на отбортовке |
| 5 | Вертикальный шаг крепёжных отверстий/пазов в ушах ФП-5 | `panel_hole_pitch_v` | между центрами соседних пазов уха |
| 6 | Отбортовка ФП-5: на всех четырёх краях ли, глубина | — (`panel_fold` = 10 [SOURCE]) | подтвердить; если боковых нет — поля можно уменьшить |
| 7 | Свободная глубина шкафа за передними стойками до задней двери/стоек | — | должна быть ≥ 393 + кабели (~80) |
| 8 | Есть ли перфорация в двери/цоколе; зазор под дверью | — | для §2 `07_rack_layout.md` |

## B. MSI EdgeXpert AI (штангенциркуль, ±0.2 мм)

| № | Что измерить | Параметр |
|---|---|---|
| 9 | Ширина × глубина × высота корпуса БЕЗ ножек | `device_width/depth/height` |
| 10 | Ножки: высота, диаметр, центр от бокового и переднего/заднего края | `device_foot_height/dia/inset` (рельсы holder'а центрируются по ним) |
| 11 | Передняя сотовая решётка: ширина, высота, отступы от краёв | `device_intake_margin_x/top/bot` |
| 12 | Нижняя щелевая решётка: поле щелей, отступ от переднего края | `device_bottom_vent_*` |
| 13 | Боковые решётки: от какого расстояния от переднего края начинаются (стойки holder'а занимают первые 25 мм) | — |
| 14 | Задняя панель: зона решётки, кнопка питания, DC-in | — |
| 15 | Фото снизу/спереди/сзади/сбоку с линейкой | — |

## C. Покупные части (при покупке)

| № | Что уточнить | Параметр |
|---|---|---|
| 16 | Arctic P14 Pro PST: фактическое межцентровое (124.5 или 125) и толщина 27 | `fan_hole_pitch`, `fan_thickness` |
| 17 | Решётка ARCTIC Fan Grill 140: толщина в месте болтов | `grille_t` |
| 18 | DC-гнездо 5.5×2.5: диаметр посадочного отверстия/резьбы, совпадение со штекером адаптера | `dc_jack_hole_d` |
| 19 | Heat-set M3: наружный диаметр | `m3_insert_hole_d` |
| 20 | EPDM-уплотнитель: толщина | `gasket_t` |
| 21 | PWM-термоконтроллеры: габарит платы, положение отверстий (под сетку M3 10 мм) | — |
| 22 | Стол принтера | `print_bed_*` |

## D. Термоконтроллеры на панели (когда придут)

| № | Что измерить | Параметр |
|---|---|---|
| 23 | Плата контроллера: ширина × высота × толщина (от выступов пайки сзади до верха кнопок/дисплея) | `ctrl_w`, `ctrl_h`, `ctrl_d` |
| 24 | Окно под дисплей и кнопки: размер и смещение от центра платы (если не «плата минус 3 мм») | `ctrl_win_w/h`, `ctrl_win_dx/dz` |
| 25 | Зазор между стеклом закрытой двери и лицевой плоскостью ФП-5 (рамка выступает на `bezel_d` ≈ ctrl_d + 4.5; нужно ≤ door_gap − 3) | `door_gap` |

Полоса над вентилятором под рамку: 221.5 − `shelf_top_z` − 150. При
`shelf_top_z` = 25 это 46.5 мм, при 40 — 31.5. Чем ниже полка относительно
панели, тем больше места: выбирать положение полки с этим расчётом (п.2).

## Как вносить

```sh
# scad/params.scad: заменить undef на измеренное, например
#   rack_opening_w = 451;  shelf_top_z = 30;  shelf_depth = 380;  panel_t = 1.2;  panel_hole_pitch_v = 31.75;
#   ctrl_w = 58;  ctrl_h = 34;  ctrl_d = 18;  door_gap = 35;
./scripts/export_all.sh          # STL/PNG без PREVIEW, чертежи с реальными размерами
# в выводе должны быть строки [FIT] и ни одной ERROR: Assertion
```

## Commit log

2026-10-03 Параметрический проект: 2× MSI EdgeXpert в 4U с раздельным охлаждением (предварительная модель)
    Этапы 1–5 по ТЗ: анализ (MSI EdgeXpert, исходник spark-rack-10 holder,
    2 фото корпуса), размерная схема (SVG/PNG), holder под крепление к дну 4U,
    воздуховод 140→MSI (smoothstep-конфузор, разрезной вариант), рамка
    вентилятора, сборка/exploded, STL-экспорт, BOM, таблица размеров,
    инженерная оценка аэродинамики. Все размеры корпуса и часть р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
    [assembly.scad, duct.scad, duct.stl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]
2026-10-03 v2: 5U-модуль в 18U шкафу вместо 4U-корпуса
    - ТЗ v2 (docs/TZ.md), исходное ТЗ в архиве (docs/TZ_v1_chassis.md), CLAUDE.md
    с принятыми решениями, открытыми вопросами и журналом.
    - params.scad: rack-параметры (rack_opening_w, shelf_top_z, shelf_depth,
    panel_t, panel_hole_pitch_v) = undef; rack_checks() — assert вместо echo,
    сборка не собирается на выдуманных числах; chassis_* удалены.
    - Вентилятор Arctic P14 Pro PST 140×27 (пазы ±0.5 под 124.5/125), ось =
    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
    [assembly.scad, base_plate.scad, bypass_baffle_050_PREVIEW.stl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]
2026-10-03 v2.1: термоконтроллеры на лицевой стороне ФП-5 в печатных рамках
    - ctrl_bezel.scad: рамка под контроллер (карман по ctrl_w/h/d, окно под
    дисплей/кнопки, задняя стенка-изолятор, лапки с heat-set M3, вырез под
    кабели); рендерится только при известных габаритах контроллера.
    - params.scad: секция 8a (ctrl_w/h/d, окно, door_gap = undef), производные
    bezel_*, strip_above_fan = panel_h − shelf_top_z − 150, ctrl_checks()
    (полоса над вентилятором, door_gap − 3, keep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
    [assembly.scad, base_plate.scad, ctrl_bezel.scad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]
